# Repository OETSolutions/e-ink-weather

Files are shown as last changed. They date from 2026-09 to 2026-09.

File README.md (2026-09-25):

# Aether — Weather Display

A wall-mounted e-ink weather display. An ESP32 drives a 5.76″ 920×680 black-and-white
e-paper panel that shows current conditions, a multi-day forecast, and readings from
Home Assistant — configured from a browser-based layout editor with no code and no
recompiling.

<p align="center">
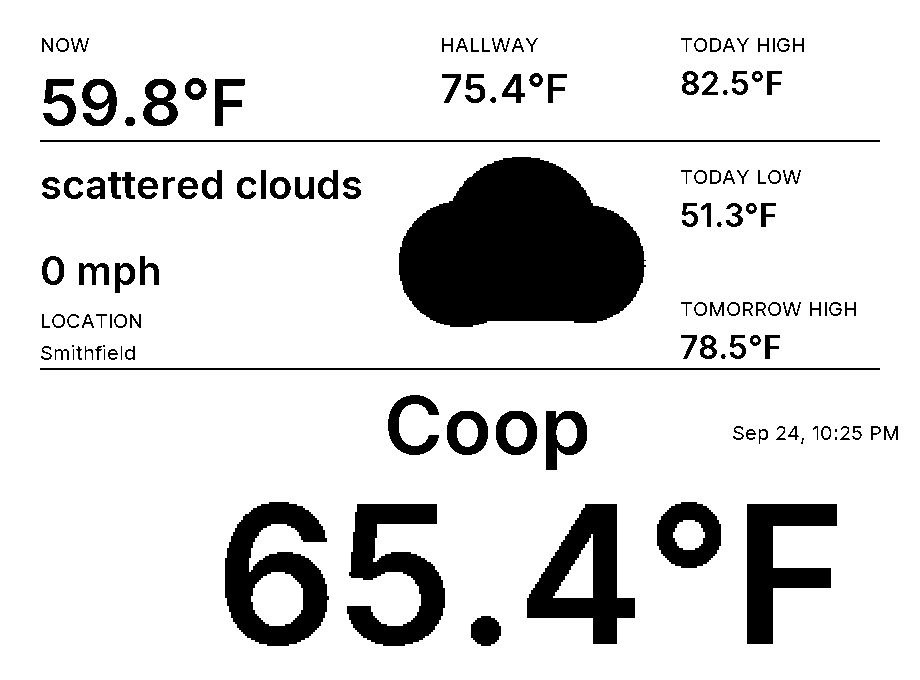
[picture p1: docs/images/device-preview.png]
The panel preview from the layout config app: temperature, conditions, the Home Assistant 'Hallway' reading, forecast highs/lows and the time of the last update
  
</p>

<p align="center"><em>What the glass shows, captured from the layout editor's preview. Everything on
screen — headings, boxes, dividers, icons and values — is placed by the layout editor below, not
hard-coded in the firmware.</em></p>

<table>
<tr>
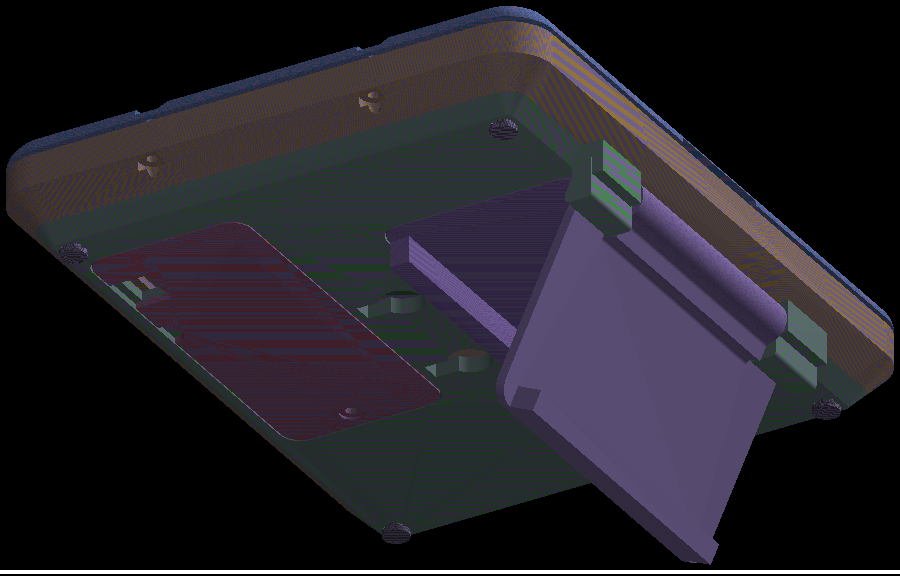
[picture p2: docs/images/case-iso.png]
CAD render of the case from an angle
<td width="50%"></td>
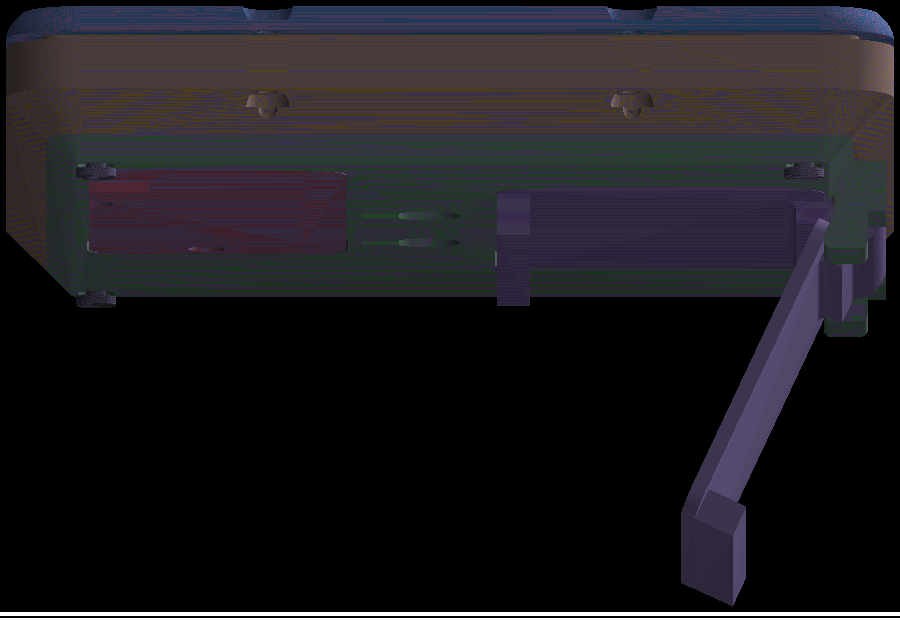
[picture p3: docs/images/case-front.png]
CAD render of the case from the side/front, showing the printed kickstand
<td width="50%"></td>
</tr>
<tr>
<td align="center"><em>Case, rear cover and printed hinge (CAD)</em></td>
<td align="center"><em>Side profile with the folding kickstand (CAD)</em></td>
</tr>
</table>

Built by **OETSolutions**.

---

## What it is

The device fetches weather from OpenWeatherMap and readings from Home Assistant, draws
them onto an e-ink panel that keeps its image even when unpowered, and serves its own
configuration web app. You point a browser at the display's IP address, arrange the
layout visually, and save — the device stores the layout and redraws.

It runs two ways:

- **Mains / always-on** — stays awake, serves the web app, and refreshes on a schedule.
- **Battery** — wakes on an interval, fetches, redraws, and goes back to deep sleep.

Power source is detected automatically from the battery voltage, and can be overridden.

## Features

- **Visual layout editor** in the browser — drag, resize and bind value boxes on a
  to-scale 920×680 canvas that shows the real 1-bit output.
- **Live preview with real data** — the editor asks the device what it actually resolved,
  so the preview matches the panel instead of guessing.
- **Two independent refresh cadences** — Home Assistant on a fast interval, OpenWeatherMap
  on a slower one (its data only updates ~every 10 minutes and its free tier is capped).
- **Multiple pages** with scheduled auto-rotation, each page with its own layout and dwell.
- **Data bindings** — OWM current conditions and forecast, Home Assistant entities (REST),
  each with per-field formatting (decimals, prefix/suffix, fallback) and thresholds.
- **Alerts** — user-defined per-field thresholds *and* official OWM severe-weather alerts.
- **Any weather product** — One Call 3.0 or the free Current + 5-day/3-hour endpoints,
  auto-detected from the API key.
- **Partial refresh** — only changed values are redrawn, with a periodic full refresh to
  clear ghosting.
- **Captive-portal and BLE provisioning** — no credentials are ever compiled in.
- **Firmware update over the network**, from GitHub releases or by uploading a `.bin`
  from the browser, with rollback protection.
- **Thermal guard** and a **last-good-image** policy: a failed fetch or an out-of-range
  temperature leaves the previous screen up rather than drawing garbage.

## How the pieces fit together

```
                    ┌─────────────────────────────┐
   browser ────────▶│  config web app (TypeScript) │  layout editor, live preview,
   (editor)         │  runs in browser OR on-device│  credentials, firmware update
                    └──────────────┬──────────────┘
                                   │ REST  (config, artwork, values, OTA)
                    ┌──────────────▼──────────────┐
   internet ───────▶│   ESP32 firmware (ESP-IDF)   │──SPI──▶ e-ink panel 920×680
   OWM, GitHub      │   fetch · render · serve     │
                    └──────────────┬──────────────┘
   Home Assistant ────────────────┘  (REST)
```

The **firmware never invents a position or a label.** The web app renders the static layer
of each page (backgrounds, headings, box outlines, icons) to a 1-bit bitmap and uploads it;
the ESP32 stores it and stamps only the *changing values* on top at each refresh. That means
a layout change ships instantly — no firmware rebuild — while the device keeps full control
of what it draws.

## Repository layout

```
eink_weather/
├── code/
│   ├── firmware/            ESP-IDF project (PlatformIO), C
│   │   ├── components/      app, api, epd, net, prov, webui, …
│   │   ├── lib/             pure, host-testable logic (datasrc, layout, owmcount, …)
│   │   ├── test/            ~510 host unit tests (run on your Mac, no hardware)
│   │   ├── tools/           generators (fonts, icons, QR, boot logo) and bench scripts
│   │   ├── assets/          generated data blobs
│   │   └── platformio.ini   pinned ESP-IDF 5.5.x toolchain
│   ├── webapp/              layout config app (TypeScript, Vite)
│   │   └── src/             model, canvas/editor, ui, transfer, presets
│   ├── docs/                spec + implementation plan
│   └── tools/               fixture / secret-header generators
├── work/                    CAD (FreeCAD), FPC and datasheet study, case renders
└── docs/images/             images used by this README
```

## Building

### Firmware

```sh
cd code/firmware
pio run                     # build
pio run -t upload           # flash over USB
pio test -e native          # host unit tests (no hardware needed)
```

ESP-IDF **5.5.x** is pinned in `platformio.ini` (both the framework and the platform —
floating either one breaks the build on a clean machine). The app image is ~1.8 MB, and
**the embedded web app shares the OTA slot**, so its size is budgeted and checked at build
time.

Secrets (WiFi, OWM key, HA URL/token) are **never compiled in** — they are entered on the
device (captive portal or BLE app) and stored in NVS. A per-machine header is generated
from a gitignored file for bench use only.

### Web app

```sh
cd code/webapp
npm install
npm run dev                                   # dev server, proxies /api to the device
npm run build:device                          # build + embed into ESP32 flash
EINK_DEVICE=http://192.168.2.34 npm run dev   # point the proxy at a device
```

The built app is embedded in the firmware, so **a web-app change is not live on the device
until you rebuild and reflash** — `npm run build:device` regenerates the embedded bundle,
which the next firmware build picks up.

### Flashing a running device over the network

Three ways, depending on the situation:

| Method | Use it when |
|---|---|
| `pio run -t upload` | The board is on USB. |
| `POST /api/firmware` | You have a `firmware.bin` and the device is on the LAN. |
| `POST /api/ota/update` | You published a GitHub release and want the device to pull it. |

The LAN upload takes the raw image over HTTP:

```sh
curl --data-binary @.pio/build/esp32dev/firmware.bin http://<device-ip>/api/firmware
```

Both network paths leave the new image **on probation**: the bootloader reverts to the
previous image unless the new one both boots *and* completes a refresh. Both are gated by
the optional access token (they replace firmware — a device takeover otherwise).

## Configuration

Open `http://<device-ip>/` in a browser. The editor covers:

- **Location** — a map picker for exact coordinates, plus an optional zip code.
- **Layout** — the canvas editor: value boxes, dividers, headings, background pictures.
- **Pages** — rotation order, per-page dwell, and the two refresh cadences.
- **Weather product** — auto / One Call 3.0 / free endpoints.
- **Credentials** — OWM key and Home Assistant URL/token (stored on the device).
- **Access** — an optional token that gates every mutating request.
- **Firmware** — check for updates, or upload a `.bin` directly.

### The two refresh cadences

Two numbers, deliberately separate:

- **Refresh Home Assistant every (seconds)** — how often the device wakes and redraws.
  Home Assistant is your own server, so this can be as short as you like.
- **Refresh weather data every (seconds)** — how often the weather is re-fetched.
  OpenWeatherMap publishes new data only about every 10 minutes and its free tier allows
  1000 calls a day, so fetching it on every wake wastes the quota on values that have not
  changed. Between weather fetches the display keeps its last readings.

A weather interval shorter than the Home Assistant one is not possible and is raised to
match it.

## Status

Complete and running on hardware. The firmware passes ~510 host tests and the web app ~220;
both are gated in CI, which also blocks releases. Firmware updates from GitHub releases are
verified end-to-end, and an image can be flashed over the LAN or by uploading it from the
browser.

## Specification

The full requirements and the implementation plan live in
[`code/docs/specs/`](code/docs/specs/) and [`code/docs/plans/`](code/docs/plans/).

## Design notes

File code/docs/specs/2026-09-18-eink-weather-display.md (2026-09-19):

# E-Ink Weather Display — Specification

**Status:** Draft for approval
**Date:** 2026-09-18
**Authors:** cbrown + Claude
**Version:** 0.1

---

## 0. How to read this document

This spec is the **single source of truth** for what gets built. Every requirement has a
stable ID (`FR-x`, `NFR-x`, `HW-x`, `IF-x`) so that tests can cite it and so that "done"
can be checked rather than assumed. Where a requirement depends on a fact that is not
verified, it is marked:

- **[VERIFIED]** — grounded in a primary source quoted in §12, or in the repo's own
  datasheets/demo code.
- **[ASSUMED]** — a reasonable engineering choice, documented so it can be challenged.
- **[OPEN]** — genuinely unresolved; carries an explicit question and a fallback plan.

Nothing in this document may be implemented on the strength of an unmarked claim.

---

## 1. Goal

Build a two-part system that puts a configurable, beautiful weather dashboard on a
5.76″ e-ink panel driven by an ESP32:

1. **Firmware** on the Good Display **ESP32-M1** board that fetches weather + Home
   Assistant data, renders the dashboard to the panel, and serves a device config API,
   OTA, and its own web UI.
2. **A web configuration app** where the user designs the layout visually — drag,
   resize, bind widgets to data sources, set alert rules, define multiple pages — and
   saves/loads configurations as local files.

**Primary intent (this phase):** display these specific values, well:

- `sensor.upstairs_hallway_temperature` (Home Assistant)
- `sensor.64b708cfe0fc_sensor_2_temperature_f` — outside coop temperature (Home Assistant)
- Current conditions and forecast for the user's location (OpenWeatherMap)
- A location picked precisely on a map, plus a zip code for the general area

…but the system must be **fully general**: any data source, any size, any position on
screen, all configured through the web UI without touching firmware.

**Non-goal for this phase:** colour/multi-panel support, touch input, frontlight (this
panel is purely reflective), and any cloud service other than OpenWeatherMap.

---

## 2. Hardware platform

### 2.1 Board: Good Display ESP32-M1

**[VERIFIED]** The board is an **ESP32-WROOM-32D** (ESP32-D0WD, dual-core, 4 MB flash,
**~320 KB usable SRAM, no PSRAM**) SPI e-paper driver board. Published outside
dimensions 66 × 48 × 1.0 mm (modeled 48 × 66 mm). It carries: USB-C (via **CH340C**
USB-serial), 3.7 V Li-ion connector (SH1.0) with **LTC4054** charger, power switch,
microSD socket, a KEY button, RST/BOOT buttons, a frontlight circuit (unused here), touch
FPC connectors (unused here), and the **P5 24-pin e-paper FPC**.

### 2.2 Panel: GDEH0576T81

**[VERIFIED]** 920 (H) × 680 (V) px, **198 dpi**, active area 117.668 × 86.972 mm,
outline 125.4 × 99.5 × 0.9 mm, 28.08 g. Controller **SSD2677**. Purely reflective — no
frontlight, no touch. Native orientation **landscape**.

- **Operating temperature 0…50 °C**; storage −25…60 °C. **[VERIFIED]**
- **600 mAs** typical per panel update; **1–3 µA** deep-sleep current. **[VERIFIED]**

> **HW-1** The firmware shall treat **0 °C as a hard lower bound for reliable
> operation**, and shall surface a warning state rather than render garbage if the
> controller's reported temperature is outside its operating range.
>
> **[MEASURED 2026-09-18 — the guard needs a fourth state.]** On this hardware the
> SSD2677's internal sensor does **not** return live ambient temperature: `0x40` TSC
> reads a constant **−15 °C**, `0x43` TSR a constant **−1 °C**, and the datasheet's TSE
> offset register (`0x41`) moves **neither** across all 8 codes. This is not a transport
> fault — the same read path returns the datasheet-correct `0x07` from REV (`0x70`) and
> `0x00` from an unused register, and REV is the documented power-on value. The panel's
> I²C external-sensor lines (`TSCL`/`TSDA`, pins 6/7) reach GPIO22/21, but GPIO21 doubles
> as the microSD `CS` and no external sensor is fitted.
>
> Consequence: **an unreadable sensor must not be treated as cold.** Folding it into
> `THERMAL_TOO_COLD` (the plan's first draft) makes the guard block *every* render
> forever on any unit that reports a constant — which is exactly what this bench unit
> does. The guard therefore returns `THERMAL_UNKNOWN` for an absent/unusable source, and
> the caller renders and logs. `THERMAL_TOO_COLD`/`TOO_HOT` are reserved for readings
> that actually came from a live source.

### 2.3 Pin map — the hardware contract

**[VERIFIED]** Decoded from the schematic (`code/ESP32-M1-SCH-20260307.pdf`) and
cross-checked against both the vendor demo and Espressif's `pins_arduino.h`. The
schematic labels module pins with Arduino *analog* aliases, which is why the table looks
unusual.

| Function | Arduino alias | GPIO |
|---|---|---|
| EPD **BUSY** | A14 | **13** |
| EPD **RES / RST** | A15 | **12** |
| EPD **D/C** | A16 | **14** |
| EPD **CS** | A17 | **27** |
| EPD **SCLK** | — | **18** |
| EPD **SDI / MOSI** | — | **23** |
| microSD **CS** (`SPI_CS_SD`) | — | **21** |
| GT30 font chip **CS** (`SPI_CS_GT30`) | A13 | **15** |
| **VBAT sense** (`VREF`, R8 300K / R9 1M divider) | A19 | **26** |
| KEY button (`KEY1`) | A18 | **25** |
| USB serial TX / RX | — | 1 / 3 |

> **HW-2** The e-paper, microSD and (if populated) the GT30 font chip **share one SPI
> bus**. Firmware shall arbitrate the bus with per-device chip-selects and shall never
> drive two CS lines low simultaneously.

> **HW-3 Battery/USB auto-detection.** The user requires automatic detection of
> battery vs. mains. **No dedicated USB-present or charge-status pin is confirmed
> available** — the `CHRG` net's destination GPIO could not be confirmed from the
> schematic, and `CHP_PU`/`SENSOR_VP`/`SENSOR_VN` turned out to be the module's own pin
> names, not board nets. **[VERIFIED: absence of confirmation]**
>
> Primary method: read the **VBAT sense network** — `VREF` = VBAT × 1 M/(300 K + 1 M) =
> **VBAT × 0.769**, on **GPIO26**. Interpretation:
> - VBAT ≥ ~4.15 V and slowly rising → on USB/charging.
> - VBAT ≤ ~4.10 V and falling → on battery.
> - **[ASSUMED]** these thresholds; they are Li-ion-typical but must be measured on the
>   real unit and made configurable.
>
> **Critical caveat [VERIFIED]:** GPIO26 is **ADC2_CH9**, and on classic ESP32 **ADC2 is
> unusable while WiFi is active** (Espressif documents this). Therefore the battery
> reading **must be taken before WiFi is brought up** (or after it is torn down), and
> the design must never read the ADC mid-session while connected. This constraint shapes
> the boot sequence (§5) and is a genuine architectural driver, not a detail.

> **HW-4** Firmware shall **probe at runtime** whether the GT30 font chip responds, and
> shall not depend on it (see HW-6). **[VERIFIED 2026-09-18 ON HARDWARE: the schematic
> silk reads `FONT - GT30L32S4W (Reserve)`, but the chip IS POPULATED on the ESP32-M1.**
> The probe reads the 8×16 ASCII glyph for `'A'` at `0x1DD990` and matches it
> byte-for-byte against LibDriver's reference. The chip has **no read-ID command** (only
> `0x03` read and `0x0B` fast-read), so presence is established by reading known content —
> a floating MISO cannot reproduce a real glyph. Data returns on **SPI_MISO = GPIO19**,
> wired to the GT30's pin 2 (`SO`).]

> **HW-5** Panel driving shall **preserve the vendor's exact undocumented init
> register sequence**. **[VERIFIED]** The public SSD2677 datasheet (Rev 1.1) documents
> only ~20 commands; the vendor's `EPD_init()` writes `0x00 PSR`, `0x30`, `0x62 HTOTAL`,
> `0x65 GSST`, `0xE0`, `0xE6`, `0xE7`, `0xE9`, **none of which appear in the datasheet**.
> They are vendor-proprietary. The firmware must reuse them verbatim, may not
> "clean up" the driver from the datasheet, and must be able to reproduce the vendor
> demo's output exactly as a regression baseline.

### 2.4 Framebuffer format

**[VERIFIED]** The vendor demo's image arrays are `unsigned char gImage_N[78200]` =
920 × 680 / 8, **1 bit per pixel, MSB-first** (78,200 bytes = 76.4 KiB). The demo then
expands 1 bpp → **2 bpp (4 grey levels)** before writing register `0x10` (DTM), which the
SSD2677 datasheet confirms is a 2-bit-per-pixel buffer.

> **HW-6** The rendering pipeline's canonical on-wire format shall be **1 bpp, 78,200
> bytes, MSB-first, row-major**. A 4-grey 2 bpp buffer (152.8 KiB) exceeds comfortable
> headroom alongside WiFi/TLS buffers on a 320 KB part **[ASSUMED: must be measured]**;
> 4-grey output, if used, shall be produced via the demo's 1→2 bpp expansion so only one
> 1 bpp buffer need exist in RAM.

### 2.5 SPI and transfer performance

> **HW-7** **[VERIFIED: the SSD2677 datasheet's entire SPI timing table reads "TBD"]**
> There is **no published maximum SPI clock**. The vendor demo uses **bit-banged
> software SPI**, which is very slow for a 78,200-byte frame.
>
> Plan: bring up the driver on **software SPI first** (proven, matches the demo), then
> move to **hardware SPI** as a measured, incremental optimization with a known-good
> reference image and a visible failure signal. The hardware-SPI clock is **[OPEN]** and
> shall be a configurable constant tuned against real hardware, defaulting conservatively.

---

## 3. System architecture

### 3.1 Two deliverables, one contract

```
 ┌────────────────────────┐         ┌───────────────────────────────┐
 │  WEB CONFIG APP        │         │  ESP32 FIRMWARE               │
 │  (browser, offline-cap.)│        │  (ESP32-M1)                   │
 │                        │         │                               │
 │  • 920×680 layout canvas│  HTTP  │  • config API (REST)          │
 │  • drag / resize       │ <─────> │  • NVS persistent storage     │
 │  • data binding        │  /api   │  • data sources: OWM, HA      │
 │  • alert rules         │         │  • renderer                   │
 │  • pages               │  Files  │  • EPD driver                 │
 │  • SAVE / LOAD files   │ <─────> │  • web UI (same app, built-in)│
 └────────────────────────┘         └───────────────────────────────┘
        (also served BY the device — user chose "both")
```

### 3.2 Rendering architecture — the load-bearing decision

The user chose: **static pre-render + on-device values**, while explicitly asking to
*"retain the ability to do on-device easily if this becomes preferable in the future."*

> **FR-1 — Renderer abstraction.** The system shall define a **renderer interface** with
> (at least) two implementations behind it:
> 1. **Composite renderer (primary):** the web app pre-renders the *static* layer
>    (background, frames, labels, icons, static text) to a 1 bpp 78,200-byte bitmap,
>    uploads it once; the firmware stores it and blits it each refresh, then draws only
>    the *dynamic value fields* on top.
> 2. **Full on-device renderer (deferred):** the firmware consumes the layout spec and
>    renders everything itself, including fonts and text layout.
>
> No code outside the renderer interface may assume which implementation is active.

> **FR-2 — Field model.** A layout is a set of **widgets**, each with a geometry
> (x, y, w, h), a **data binding**, and a **rendering role** (static or dynamic). Widgets
> marked dynamic must be re-drawn on every refresh from current data.

> **FR-3 — Value drawing.** On-device dynamic value drawing shall support at minimum:
> numeric and text values, alignment (left/centre/right, top/middle/bottom), a
> configurable font size, and a "fit to box" mode that shrinks text to fit its widget
> rather than overflowing. **[ASSUMED: this is the minimum for the listed use case.]**

### 3.3 Fonts

The user requires fonts that *"look extremely good"* and pointed at the board's GT30
font chip.

> **HW-6 / FR-4** The GT30L32S4W is marked **"(Reserve)"** on the schematic — a
> reserve/DNP footprint — so it **cannot be assumed present**. The firmware shall:
> 1. **Probe** for it at boot and cache the result;
> 2. **Use it only if present** and only for glyphs it actually provides;
> 3. **Always retain a built-in flash-resident font path** that works with the chip
>    absent.

> **FR-4a — Font strategy (DECIDED). [VERIFIED: library characteristics]**
> **Pre-rendered 1-bit bitmap font atlases, generated at build time, baked into the
> firmware and used by the web app's preview.** Rationale and specifics:
> - **Why not a runtime font engine:** the panel is 1-bit (HW-6) at 198 dpi, where
>   **anti-aliasing is impossible** — grey fringes become visible dots. The crispest
>   result comes from glyphs **hinted and rasterised for the exact pixel size** once, at
>   build time, then blitted. A runtime TTF rasteriser burns RAM/flash and produces
>   softer output. **[ASSUMED — strong engineering judgment, not a datasheet claim.]**
> - **Why the atlas approach beats a generic library:** `U8g2` **[VERIFIED: widely used
>   for monochrome displays; Unicode-capable]** has excellent built-in fonts but pulls in
>   a rendering model the vendor's undocumented EPD init does not need. Baking our own
>   atlases keeps the firmware free of a display library that could fight the vendor
>   sequence (HW-5) and lets the **exact same atlas** drive the web-app preview, which is
>   what makes NFR-4 ("preview matches panel bit-for-bit") achievable.
> - **Atlas generation:** a build step converts chosen faces (Inter / IBM Plex / Roboto
>   class — clean, high-x-height, superb at small sizes **[ASSUMED]**) into 1-bit atlases
>   for a fixed ladder of sizes tuned to 198 dpi (e.g. body ≈ 18–22 px, value ≈ 56–72 px).
>   Threshold, do **not** dither, for text — dithering makes type look dirty.
> - **The GT30 chip, if populated, is an accelerator only** — never a dependency.
>
> **FR-4b** Only glyphs actually used by a configuration need to be present, so atlases
> may be **subset per configuration** at push time to save flash. **[ASSUMED: defer until
> flash pressure is measured; full ASCII+latin-1 first.]**

### 3.4 Data sources — pluggable

> **FR-5** The firmware shall define **one data-source interface** with **two
> interchangeable implementations**: **Home Assistant REST** and **MQTT**. The user
> chose "both, pluggable" and both shall exist; REST ships first. Swapping must be a
> config change, not a code change.

> **FR-5a — HA REST, and the key optimisation. [VERIFIED]**
> - Auth is `Authorization: Bearer <long-lived access token>`, obtained from the HA user
>   profile page. `GET /api/states/<entity_id>` returns one entity as
>   `{entity_id, state, last_changed, last_updated, attributes{...}}`; a **404 means the
>   entity does not exist** — which gives the web app a clean way to *validate* an entity
>   id the user types (FR-23).
> - **`GET /api/states` returns *every* entity in one array.** That is one round-trip but
>   the payload is large (hundreds of entities) and would be a needless memory spike on a
>   320 KB part. **Use it only in the web app** (for entity discovery), never on-device.
> - **The on-device design: `POST /api/template`.** HA will render a template server-side
>   and return the result as plain text. So the device sends **one small POST** naming
>   exactly the entities its current layout needs, and receives **one small response** —
>   e.g. `{{ states('sensor.upstairs_hallway_temperature') }}|{{ states('sensor.64b708cfe0fc_sensor_2_temperature_f') }}`
>   ⇒ `68.4|41.2`. This is strictly better than N per-entity GET calls and far better than
>   pulling `/api/states`. **The device derives the template from its own layout's bound
>   entities, so adding a widget needs no firmware change.** JSON output is also possible
>   via a template that emits a JSON object, if structured values are preferable.
> - HA weather forecasts are available via
>   `POST /api/services/weather/get_forecasts?return_response` with
>   `{"entity_id": "...", "type": "daily"}` **if** the user later wants HA-sourced
>   forecasts alongside OpenWeatherMap. **[Not required for this phase.]**
>
> **FR-5b — Timestamp hygiene.** HA `state` values are **strings**, and a sensor can be
> `"unavailable"`/`"unknown"`. The data layer shall therefore validate, not cast blindly,
> and shall carry `last_updated` through so the layout can show and the alert logic can
> detect **stale** data. **[ASSUMED — this is the main correctness trap in consuming HA.]**

> **FR-5c — MQTT, and its real cost. [VERIFIED]** An HA entity's state is **not**
> published to MQTT by default. The user must enable the **`mqtt_statestream`**
> integration (plus the `mqtt` integration, i.e. a broker such as Mosquitto). Its
> documented topic form is **`base_topic/domain/entity/state`** — e.g.
> `homeassistant/sensor/upstairs_hallway_temperature/state` — with optional
> `publish_attributes` and `publish_timestamps` adding sibling topics
> (`.../last_updated`, and one topic per attribute).
> - Values are **JSON-serialised before publishing**, so a string state arrives quoted
>   (`"on"`). The parser must account for this.
> - **`mqtt_statestream` is flagged in HA's own docs as a *legacy* integration**
>   ("community maintained"). **[VERIFIED]** The spec shall therefore **not depend on it
>   as the only path** — which is exactly why REST ships first and MQTT is the pluggable
>   alternative (FR-5). The setup guide shall state the HA-side configuration the user
>   must add.
> - **Deep-sleep fit [ASSUMED, engineering judgment]:** MQTT needs a persistent broker
>   session, and a device that sleeps has to reconnect each wake — so MQTT's push
>   advantage largely evaporates in battery mode and it is **most useful in always-on
>   mode**. This informs FR-5's "REST first" ordering and shall be stated in the docs
>   rather than discoverered later.

> **FR-6 (OpenWeatherMap)** The provider shall support **both** OpenWeatherMap products —
> **One Call API 3.0** and the legacy free **Current Weather + 5-day/3-hour Forecast**
> — selectable by **config toggle**, and shall **auto-detect from the API key where
> possible** (probe One Call 3.0; fall back on the documented not-subscribed response).

> **FR-6a [VERIFIED]** The primary endpoint is
> `https://api.openweathermap.org/data/3.0/onecall?lat={lat}&lon={lon}&exclude={part}&units={units}&appid={KEY}`.
> - `lat`/`lon` **required**; `units` optional (`standard`|`metric`|`imperial`;
>   **`imperial` gives °F and mph**, which is what the user's entities use).
> - Returns **current weather, minute (1 h), hourly (48 h), daily (8 d), and
>   government weather alerts** — so **alerts come free with the same single call**,
>   which is why One Call 3.0 is the preferred product (FR-14).
> - **One Call 3.0 requires the separate "One Call by Call" subscription, which includes
>   1,000 calls/day free but requires a card on file.** **[VERIFIED]** At a 10–15 minute
>   refresh that is ~96–144 calls/day, comfortably inside the free tier. The firmware
>   shall nonetheless **count and cap daily calls** and surface the count in `/api/status`,
>   so a bug cannot silently burn the quota.
> - The free legacy endpoints (Current Weather `data/2.5/weather`, 5-day/3-hour forecast
>   `data/2.5/forecast`) require no card but carry **no official alerts** — the exact
>   trade-off FR-7 handles.

> **FR-7** Official severe-weather alerts depend on One Call 3.0. If the configured
> product does not provide them, the alert feature shall degrade explicitly (state that
> official alerts are unavailable) rather than silently showing nothing.

### 3.5 Power and sleep

> **FR-8** Firmware shall support **both** modes, user-selectable / auto-detected
> (HW-3): **deep-sleep battery mode** and **always-on mains mode**. Battery detection
> happens **before WiFi init** (HW-2 caveat).
>
> Auto-detection is **inferred** and therefore fallible: **[VERIFIED — schematic]** this
> board has no confirmed USB-present or charge-status pin (the VBUS net and the LTC4054's
> `CHRG` output exist, but neither destination GPIO resolves), so the mode is derived from
> the VBAT divider alone. The configuration shall therefore carry an explicit
> **`powerMode`** of `'auto' | 'always-on' | 'battery'` (default `'auto'`) so the user can
> override a wrong guess. Detection shall fail **toward battery**, because sleeping too
> eagerly costs a slower refresh while failing to sleep costs the entire battery. The
> residual limitation is inherent to inferring from one signal: a pack held **flat** at
> or above the threshold is indistinguishable from mains, so a full cell whose voltage
> is not measurably falling will read as USB. That case is what the `powerMode` override
> exists for; the trend term only separates the two when the pack is actually drooping.

> **FR-9** In deep-sleep mode the device shall wake on a configurable interval, and the
> boot path shall be ordered: **read VBAT (ADC2, WiFi off) → connect WiFi → fetch →
> render → update panel → sleep**, with the panel update and sleep guaranteed even if a
> fetch fails (§5).

### 3.6 E-ink lifetime

The user explicitly requires proper lifetime preservation *and* demo-like speed/quality.

> **FR-10** **[VERIFIED — panel datasheet §7.5]** The panel **must be refreshed at least
> every 24 hours** or "Ghosting"/"Image Sticking" may occur. The firmware shall enforce
> a **daily full refresh** regardless of the configured update interval.

> **FR-11** The firmware shall implement a **partial-refresh-with-periodic-full-refresh**
> strategy: mostly partial updates for speed and low flicker, with a full refresh after a
> configurable number of partials **[ASSUMED default 5, per the vendor demo's comment]**
> and at the daily boundary (FR-10).

> **FR-12** The firmware shall **always issue the deep-sleep command** after an update
> and shall re-initialise before every full update, per the vendor's documented
> requirements **[VERIFIED]**. It shall not leave the panel powered between updates.

> **FR-13** The firmware shall read the controller's internal temperature (command
> `0x40`, which returns °C directly per the datasheet) and apply the vendor's
> temperature-compensated waveform selection, preserving the demo's behaviour.
>
> **[MEASURED 2026-09-18]** `0x40` on this unit returns a constant −15 °C regardless of
> ambient, so the waveform it selects is a *fixed* cold-temperature LUT (the `<=5 °C`
> entry, value 232), not a temperature-tracking one. The vendor demo has the same
> exposure and simply never noticed. This is safe — the LUT ladder is monotone and the
> cold entry is a valid waveform — but it is **not** compensation, and the code must not
> claim it is. Revisit if a working ambient source (external I²C sensor, or a live
> internal reading on a different unit) becomes available. See HW-1.

### 3.7 Alert bars

> **FR-14** The system shall support **two** alert mechanisms, both per the user's choice:
> 1. **User-defined threshold rules** per bound field (e.g. *temp_f > 100 → red bar*,
>    *wind_mph > 25 → amber bar*), editable in the web UI, working for **any** bound
>    source including Home Assistant entities.
> 2. **OpenWeatherMap official severe-weather alerts** rendered when present (subject to
>    FR-7).
>
> Alert rendering shall be a first-class widget type with configurable severity levels,
> colours (mapped to grey levels on a mono panel), and text.

### 3.8 Paging

> **FR-15** The system shall support **multiple pages**, each with its own layout,
> bindings, and refresh interval. **[VERIFIED: user chose scheduled auto-rotation]** The
> device shall cycle pages automatically on a configurable schedule.

> **FR-16** Paging must be optional; a single-page configuration shall behave identically
> to today's requirement.

### 3.9 Initial layout (this phase's deliverable)

> **FR-17** The project shall ship a **default layout** implementing the user's stated
> intent: upstairs hallway temperature, outside coop temperature, current conditions,
> forecast, and location/zip display — with sensible alert rules pre-configured.

---

## 4. Web configuration app

### 4.1 Delivery

> **FR-18 [VERIFIED: user chose "both"]** The app shall be buildable two ways from one
> codebase:
> 1. **Local dev:** `npm run dev` for rich, fast editing against a device on the LAN.
> 2. **Embedded:** the production build is flashed into the ESP32 and served by the
>    device itself at its IP, with no install.

> **FR-19** Both modes shall share the same API client contract so behaviour is identical.

> **FR-19a — Framework (DECIDED): vanilla TypeScript + Vite, no UI framework.**
> Rationale:
> - The app is **one screen with one canvas** plus a property panel. A component
>   framework (React/Vue/Svelte) adds a build/runtime dependency and bundle weight for
>   little benefit here, and bundle weight matters because this build must also be
>   **served from an ESP32's 4 MB flash** (FR-18).
> - The hard part is canvas interaction (drag, resize, snapping), not component
>   composition. **A small purpose-built interaction layer over a `<canvas>` is more
>   predictable than fighting a DOM-based drag library** for pixel-exact 1-bit output.
> - **Vite** gives fast dev with HMR (`npm run dev`) and a small production build with
>   an easy single-file asset step for embedding in firmware. **[VERIFIED: Node 26 /
>   npm 11 present locally.]**
> - Escape hatch recorded: because the state layer is plain TS + a typed config model
>   (§IF-1), a framework could be introduced later without rewriting the model.
>
> **[ASSUMED — this is a judgment call, flagged deliberately.]** If the user prefers
> React, React + `react-rnd` is the natural alternative; nothing else in the spec depends
> on this choice.

### 4.2 Editor requirements

> **FR-20** The editor shall present a **fixed 920 × 680 pixel canvas** representing the
> panel exactly, with zoom/pan, and shall render a truthful 1-bit preview (what you see
> is what the panel shows).

> **FR-21** Widgets shall support **drag**, **resize** (edge/corner handles), **grid
> snapping**, **alignment guides**, and a **z-order** control.

> **FR-22** A **property inspector** shall expose, per widget: geometry, data binding,
> static/dynamic role, font/size/alignment, formatting (units, decimals, prefixes),
> and alert rules.

> **FR-23** The app shall support **data binding** to: OWM current fields, OWM forecast
> fields, OWM alerts, and arbitrary Home Assistant entities (chosen by entity id, with a
> discovery/validation step against the configured HA instance).

> **FR-24** The app shall include a **map picker** for precise lat/lon, and a **zip code**
> field for general location.

> **FR-25** The app shall manage **multiple pages** and their rotation schedule.

> **FR-26** The app shall **save and load configurations as local files**, and push a
> configuration to the device. **[VERIFIED: user requirement]**
>
> **FR-26a — Format: download/upload JSON, not the File System Access API. [VERIFIED]**
> MDN classes `showSaveFilePicker()`/`showOpenFilePicker()` as **"Limited availability …
> not Baseline … Experimental"**, requiring a **secure context (HTTPS)** and transient
> user activation. That rules it out as the primary mechanism for a device served over
> plain HTTP on a LAN IP. **Design:** a versioned `.json` config downloaded/uploaded via
> a normal anchor/`<input type=file>`, which works everywhere; optionally *enhance* with
> the File System Access API **only when `window.showSaveFilePicker` exists** (progressive
> enhancement, never required). `localStorage` holds working state and recent configs.
>
> **FR-26b** A saved config file shall be self-describing: it embeds `schemaVersion` and
> a `generator`/`createdAt` stamp so a future version can migrate it or refuse it clearly
> rather than silently mis-reading it.

> **FR-27** The app shall show a **live or on-demand preview** rendered with real fetched
> data before pushing to the device.

---

## 5. Firmware behaviour

### 5.1 Boot / wake sequence

> **FR-28** The boot path shall be, in order:
> 1. Initialise NVS, load config.
> 2. **Read VBAT sense (GPIO26) with WiFi off** → decide power mode (FR-8, HW-3).
> 3. Initialise panel and render the *last known* state **or** a "connecting" state
>    (so a network failure never leaves a stale/blank panel).
> 4. Bring up WiFi (station; captive portal if unconfigured).
> 5. Fetch all enabled sources (with per-source timeout and retry).
> 6. Render the current page and update the panel (partial or full per FR-11).
> 7. Persist any needed state; deep-sleep if in battery mode.

> **FR-29** **Every** failure mode shall leave the panel showing the last good image
> plus a visible, discreet error indicator — never a blank panel or a wedged device.

### 5.2 Provisioning

> **FR-30 [VERIFIED: user chose Option 1 + BLE]** The device shall support:
> 1. **Captive-portal provisioning** on first boot / unconfigured state — a WiFi AP where
>    the user enters WiFi credentials, the OWM API key, the HA URL and token, and
>    location. Values persist in **NVS**.
> 2. **The official ESP BLE Provisioning mobile app**, current version with full update
>    support.
>
> No credentials shall ever be committed to git.

### 5.3 Config API

> **FR-31** The device shall expose a REST API for the web app: read config, write
> config, upload the static bitmap, upload per-page layouts, trigger a refresh, read
> status (last fetch, last refresh, battery voltage, RSSI, firmware version, errors).
> Exact endpoints in §6.

### 5.4 OTA

> **FR-32** The device shall support **OTA firmware update**, authenticated, with
> rollback protection (a failed new image shall fall back to the previous working one).

### 5.5 Diagnostics

> **FR-33** The device shall expose: firmware version, uptime, free heap (minimum
> watermark), WiFi RSSI, last N errors, panel refresh counts (partial/full), and battery
> voltage history — enough to diagnose a field failure remotely.

---

## 6. Interfaces (exact contracts)

> **IF-1 Config document (JSON).** The canonical configuration is a single versioned JSON
> document owned by the web app and stored in device NVS. It shall carry a `schemaVersion`
> and be forward/backward compatible by explicit migration. Full schema in
> `docs/specs/config-schema.md` (to be written with the implementation).

> **IF-2 Static bitmap transfer.** 1 bpp, 78,200 bytes, MSB-first, row-major.
>
> **IF-2a — Mechanism (DECIDED): chunked HTTP upload, with the SD card as an offline
> path.**
> - Primary: `POST /api/bitmap` with a **chunked** body (e.g. 4 KB per request, with an
>   offset/index and a finalising commit), so a 76.4 KiB upload never needs to be buffered
>   whole on a part with ~320 KB SRAM. The device streams each chunk to flash (a dedicated
>   raw partition or a filesystem file), verifies a checksum, then atomically marks the new
>   bitmap active. **An interrupted upload must leave the previous bitmap intact.**
> - Secondary (offline / no-network): the same file can be written to the **microSD**,
>   whose socket is already present and case-accessible. This exercises HW-2's bus
>   arbitration and gives a way to update a device that will not join the network.
> - **[ASSUMED: chunk size and storage target to be confirmed once flash partitioning is
>   designed; the requirement is the streaming + atomic-swap behaviour, not the exact
>   number.]**

> **IF-3 Data-source interface.** `fetch(source) -> {value, unit, timestamp, error}`
> semantics, identical for OWM, HA-REST and MQTT, so widgets are source-agnostic.

> **IF-4 REST endpoints.** `GET/PUT /api/config`, `POST /api/bitmap`, `POST /api/refresh`,
> `GET /api/status`, `POST /api/provision`, `POST /api/ota` — final naming and payloads
> fixed during implementation, documented in `docs/specs/api.md`.

---

## 7. Non-functional requirements

> **NFR-1 Reliability.** The device shall run for weeks unattended and recover
> automatically from WiFi loss, DNS failure, TLS failure, and API errors, without a power
> cycle. This is the user's explicit complaint about the vendor demo.

> **NFR-2 Memory.** Firmware shall operate within the ESP32-WROOM-32D's ~320 KB SRAM with
> **no PSRAM**, maintaining a documented minimum free-heap watermark under worst-case
> (TLS + WiFi + render) load. A full 1 bpp framebuffer is 76.4 KiB.

> **NFR-3 Power.** Deep-sleep current shall approach the panel's 1–3 µA floor with the
> panel and radios off; the firmware shall not leak power in sleep.

> **NFR-4 Display quality.** Text shall be crisp at 198 dpi with no anti-aliasing
> artifacts; the preview in the web app shall match the panel output bit-for-bit.

> **NFR-5 Lifetime.** Panel refresh strategy shall satisfy FR-10…FR-13.

> **NFR-6 Testability.** All pure logic (data model, layout maths, alert evaluation,
> formatting, config migration, bitmap generation) shall be **unit-testable on the host
> without hardware**. Hardware paths shall be isolated behind thin interfaces.

> **NFR-7 No silent assumptions.** Every requirement carries a test that fails when the
> requirement is not met — "done" is defined by the tests, not by assertion.

---

## 8. Repository layout

**[VERIFIED: user chose the current directory]**

```
eink_weather/                  <- git root
  code/                        <- working dir
    ESP32-M1-SCH-*.pdf         (reference, unchanged)
    SSD2677(Rev1.1)N_driver_ic.pdf
    GDEH0576T81_Arduino_demo_code/   (reference, unchanged)
    firmware/                  <- NEW  PlatformIO project
    webapp/                    <- NEW  web config app
    docs/
      specs/                   <- NEW  this spec + schema/api docs
      plans/                   <- NEW  implementation plan
```

---

## 9. Tech stack

### 9.1 Firmware framework — DECIDED: ESP-IDF

**[VERIFIED]** The decision is **`framework = espidf`** in PlatformIO. Evidence:

1. **The user's crash report is real and documented.** The Arduino ESP32 TLS failures are
   not anecdote — they are a well-known class of bug with a known mechanism. Multiple
   primary issue reports on `espressif/arduino-esp32` show exactly this signature:
   - **#566** — *"Any HTTPS connection results in a stack overflow error … `***ERROR*** A
     stack overflow in task loopTask has been detected`"* the moment `client.connect()`
     runs.
   - **#1025** — *"Latest pull causing core panic and stackoverflows"*, stack overflow in
     `loopTask`.
   - **#1260** — *"SSL Handshake still an issue … Guru Meditation Error: Core 1 panic'ed
     … Stack canary watchpoint triggered (loopTask)"* during the TLS handshake.
   - **#211** — crash/panic after a TLS handshake fails, backtrace through
     `start_ssl_client` → `WiFiClientSecure::connect` → `loopTask`.
   **Root cause [ASSUMED, well-supported]: the Arduino `loopTask` runs with a small
   default stack (~8 KB) and the TLS handshake needs more.** Arduino's `loop()` model
   gives the developer no natural place to size that stack. This is precisely why the
   vendor demo appears to "crash in WiFi/SSL/webserver".

2. **PlatformIO's official ESP32 platform does not support the current Arduino core.**
   **[VERIFIED]** `platformio/platform-espressif32` issue **#1225**: *"Arduino 3.x is not
   officially supported by PlatformIO"* — the official platform remains on Arduino core
   2.x. The community workaround is the **`pioarduino` fork**
   (`https://github.com/pioarduino/platform-espressif32`), currently tracking **Arduino
   3.3.11 / ESP-IDF 5.5.5**. So an Arduino-based build would mean either depending on a
   third-party fork or pinning to a 2.x core — i.e. deliberately building on the older
   stack that has the crash bugs. **ESP-IDF, by contrast, is natively and fully supported
   by PlatformIO with no fork.**

3. **Every requirement maps to a first-party ESP-IDF component. [VERIFIED]**
   - TLS + HTTPS + certificate bundle → `esp-tls` / `esp_http_client` (+ baked CA bundle).
   - MQTT → `mqtt` client component.
   - HTTP server for the config API + device-served web UI → `esp_http_server`.
   - OTA with rollback → `esp_https_ota` + the standard dual-OTA partition table.
   - **BLE provisioning for the official app** → the `wifi_provisioning` component, which
     is *the* component Espressif's own **ESP BLE Provisioning** app (App Store / Play
     Store, "IDF v3.2 and later") is designed to talk to. This is a direct match for the
     user's requirement — no library hunting.
   - Deep sleep → `esp_sleep`.
   - Persistent config → `nvs_flash`.
   - JSON → `cJSON` (bundled).

4. **The crash class is structurally avoided, not just avoided by luck.** In ESP-IDF the
   firmware controls task creation and therefore the **stack size of every task**. The
   network work runs in a task sized for TLS, so the #566/#1260 failure mode cannot occur
   by default. This directly addresses NFR-1 and the user's stated complaint.

5. **The driver work is framework-neutral.** **[VERIFIED]** Because the vendor's EPD init
   registers are undocumented (HW-5), the firmware must *reuse the vendor's byte
   sequence* rather than adopt a third-party display library. So the usual "Arduino has
   more libraries" argument does not apply here — there is no library that helps.

6. **Testability [VERIFIED]** matches NFR-6/NFR-8 directly: ESP-IDF ships the **Unity**
   test framework and a **pytest**-driven on-device test runner, and its components can
   be built for the host, enabling the off-device unit tests the spec requires.

> **FR-35** Firmware shall be a PlatformIO project using `framework = espidf`, targeting
> the `esp32dev` board (ESP32, 4 MB flash, 320 KB RAM **[VERIFIED: matches `pio boards`]**).
> The ESP-IDF version shall be pinned explicitly in `platformio.ini` for reproducibility.
>
> **[VERIFIED: `pio pkg show platformio/framework-espidf`]** versions available to
> PlatformIO are `4.60100.0` (= ESP-IDF **6.0.1**, latest), `4.60000.0` (6.0.0),
> `3.50503.0` (**5.5.3**), `3.50400.0` (5.4.0), … Pin to the newest **5.5.x** line
> (`3.50503.0`) for this project's first release — it is mature and well inside
> component support — and treat 6.0.x as a later, deliberately-tested upgrade. **The
> pinned version is a requirement, not a footnote: an unpinned toolchain is exactly how
> a project silently changes behaviour between builds.**

> **FR-36 (counterargument, recorded deliberately)** ESP-IDF has a steeper learning curve
> and a smaller third-party-library ecosystem than Arduino. This is accepted because
> (a) the needed functionality is all first-party, (b) the display driver must be
> vendor-derived anyway, and (c) ecosystem convenience is what produced the instability
> the user is trying to escape. **If Arduino convenience is ever genuinely needed, the
> escape hatch is `framework = arduino, espidf`** — Arduino-as-a-component under ESP-IDF
> **[VERIFIED: supported by PlatformIO]**, which preserves ESP-IDF's task control while
> allowing specific Arduino libraries. This is the documented fallback, not the default.

> **FR-37** Web app: modern JS toolchain (Node 26 / npm 11 available locally
> **[VERIFIED: local environment]**). Framework choice **[OPEN — §11 Q5]**.

---

## 10. Testing strategy (defined before code)

> **NFR-8** Every requirement below shall have an automated test before it is considered
> implemented (TDD). Tests are grouped:
>
> 1. **Host unit tests (firmware, pure logic)** — run on the developer machine with no
>    hardware. Cover: config schema + migration, data-source parsing (recorded OWM/HA/MQTT
>    fixtures), alert-rule evaluation, unit/format logic, widget geometry, 1 bpp bitmap
>    encoding, page-rotation scheduling, VBAT→voltage maths.
> 2. **Hardware-in-the-loop tests (on device, manual/scripted)** — panel init produces the
>    vendor reference image; partial vs. full refresh; sleep current; WiFi reconnect
>    soak; OTA rollback; provisioning.
> 3. **Web app tests** — component tests for widgets/editor, plus end-to-end tests for
>    drag/resize/bind/save/load/push.
> 4. **Contract tests** — the web app and firmware agree on the config document and API
>    (shared fixtures, so schema drift fails a test rather than a device).
>
> **NFR-9** A **golden-image test** shall pin the firmware's rendering of the default
> layout: a known config + known fixture data ⇒ an exact expected 78,200-byte bitmap.
> Any rendering regression fails loudly.

---

## 11. Open questions

| # | Question | Status / fallback |
|---|---|---|
| Q1 | Font strategy | **RESOLVED — pre-rendered 1-bit atlases** (FR-4a); GT30 as optional accelerator only. |
| Q2 | Config save/load mechanism | **RESOLVED — download/upload JSON** (FR-26a); File System Access API as optional progressive enhancement only. |
| Q3 | Static bitmap transfer | **RESOLVED — chunked HTTP with atomic swap** (IF-2a); microSD as offline path. |
| Q4 | Firmware framework | **RESOLVED — ESP-IDF** (§9.1). Escape hatch: `framework = arduino, espidf`. |
| Q5 | Web app framework | **RESOLVED — vanilla TS + Vite** (FR-19a); React + react-rnd is the recorded alternative. |
| Q6 | GT30 font chip CS GPIO | **RESOLVED 2026-09-18 — GPIO15 (`A13`)**. Resolved by rendering the schematic at 3000 DPI and aligning the `SPI_CS_GT30` wire's x-position against the module's bottom-pin numbers, then cross-checking the alias: the pin-23 wire carries `IO15` / `A13` / `T3` / `SPI_CS_GT30`, and `pins_arduino.h` confirms `A13 = 15`. The same method reproduces the already-verified BUSY pin (A14=13), which is the control. The chip remains **DNP/reserve** — the probe still returns 0 when absent. |
| Q7 | Exact VBAT thresholds for battery/USB discrimination | **Open by design** — default 4.15 V / 4.10 V, configurable; measure on the real unit (HW-3). |
| Q8 | Is the `CHRG` charge-status net usable, and on which GPIO? | **Open** — fallback: ignore it, rely on the VBAT divider (HW-3). |
| Q9 | Chunk size + storage target for the bitmap | **Open** — resolve during flash-partition design; the streaming/atomic requirement stands (IF-2a). |
| Q10 | Font faces and the exact size ladder for 198 dpi | **Open** — pick during implementation against a printed proof; candidates in FR-4a. |

**Questions genuinely needing the user (asked 2026-09-18, resolved above):**
rendering split (→1), app hosting (→both), power (→both + VBAT detect), alerts (→both),
HA method (→both pluggable), repo layout (→`code/`), secrets (→captive portal + BLE),
paging (→scheduled rotation), project path (→`code/`), OWM product (→both + toggle).

---

## 12. Sources and evidence

- Panel datasheet: `docs/GDEH0576T81_display.pdf` (rev 1.0, 2025-04-11, 17 pp) — geometry
  §1, FPC pinout §1.5, electrical §2, optical §3, precautions/lifetime §7.
- Controller datasheet: `code/SSD2677(Rev1.1)N_driver_ic.pdf` (Rev 1.1, Aug 2023, 19 pp)
  — command table §4.5 pp.7-11, OTP/VCOM pp.9-11, AC timing §9.1 p.15 (all TBD).
- Board schematic: `code/ESP32-M1-SCH-20260307.pdf` (Altium, 2026-05-12) — pin nets,
  VBAT divider, GT30 "(Reserve)" annotation.
- Vendor demo: `code/GDEH0576T81_Arduino_demo_code/` — init sequence, 1 bpp 78,200-byte
  image arrays, temperature LUT selection, sleep discipline.
- Mechanical reconstruction + accuracy caveats: `GoodDisplay_ESP32_M1_RESEARCH*.md`,
  `GoodDisplay_ESP32_M1_reconstructed_v2/`.
- Framework evidence (§9.1):
  - Arduino-ESP32 TLS stack-overflow reports: `espressif/arduino-esp32` issues
    **#566, #1025, #1260, #211**.
  - PlatformIO Arduino-core-3.x support gap: `platformio/platform-espressif32`
    issue **#1225**; community fork `pioarduino/platform-espressif32` (Arduino 3.3.11 /
    ESP-IDF 5.5.5).
  - PlatformIO Espressif32 docs — `framework = arduino | espidf`, and Arduino-as-component.
  - ESP BLE Provisioning app listings (App Store / Google Play) — "BLE based Wi-Fi
    Provisioning from IDF v3.2 and later".
- **Still outstanding (§§ 4.2, 6, 11 Q1/Q2/Q3/Q5):** web-app framework, font strategy,
  config file format, OpenWeatherMap / HA REST-vs-MQTT specifics, bitmap-transfer
  mechanism.

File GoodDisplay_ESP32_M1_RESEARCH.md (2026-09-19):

# Good Display ESP32-M1 — mechanical reconstruction for enclosure design

## Deliverables
- `GoodDisplay_ESP32_M1_mechanical.step`: multi-body STEP assembly for direct import into FreeCAD.
- `GoodDisplay_ESP32_M1_FreeCAD.FCMacro`: native FreeCAD macro that creates named Part solids plus case-clearance helpers.
- `GoodDisplay_ESP32_M1_locations.csv`: editable mechanical location table.
- `GoodDisplay_ESP32_M1_board_outline.dxf`: board outline for sketches / enclosure workflows.

## Coordinate system
Origin is the **bottom-left PCB corner when viewing the component side straight-on**. X goes right (0–48 mm), Y goes up (0–66 mm), and Z=0 is the PCB bottom. The official site writes the outside dimensions as **66 × 48 × 1.0 mm**; the model represents that as 48 mm X × 66 mm Y × 1.0 mm Z.

## Sourced facts
Good Display's current ESP32-M1 product page specifies:
- Outside dimensions: 66 × 48 × 1.0 mm.
- USB Type-C power/data.
- 3.7 V Li-ion battery connector, SH1.0.
- Power switch.
- microSD slot.
- User button.
- Brightness adjustment resistor (RT).
- Front-light voltage select and HV switch.
- Front-light FPC.
- e-Paper FPC, P5, 24-pin.
- Touch FPCs, P6/P7.
- RESE resistor-match switch, P4.
- RST and BOOT buttons.
- ESP32-WROOM-32D module.

Espressif's ESP32-WROOM-32D datasheet specifies the module at **18.00 × 25.50 × 3.10 mm** (nominal, with dimensional tolerances in the datasheet). That known component and the official 48 × 66 mm PCB were used as independent image-scale checks.

Official references:
- Good Display ESP32-M1 product page: https://www.good-display.com/product/1068.html
- Good Display ESP32-M1 schematic listing: https://www.good-display.com/companyfile/2058.html
- Espressif ESP32-WROOM-32D / 32U datasheet: https://documentation.espressif.com/esp32-wroom-32d_esp32-wroom-32u_datasheet_en.html

## What is inferred
Good Display does **not** publish a dimensioned mechanical drawing, board STEP file, or PCB layout/gerbers on the public product/download pages I found. Therefore:
- PCB **size and thickness** are sourced.
- WROOM-32D **body dimensions** are sourced.
- Connector/switch/button **identity and function** are sourced from Good Display.
- The **XY locations**, PCB corner radius, mounting-hole positions/diameters, and most peripheral component body dimensions are reconstructed from the official straight-on product photograph and standard package proportions.

The STEP/macro intentionally use simple bounding solids rather than pretending to know exact manufacturer part numbers for every connector. For a case, that is generally preferable: it exposes the wall-opening and interference geometry clearly.

## Location table summary
Dimensions below are the model values. For box solids, X/Y is lower-left. Cylinders use center X/Y.

| Item | X | Y | Size / dia | Z height | Confidence |
|---|---:|---:|---|---:|---|
| ESP32-WROOM-32D | 24.0 | 34.2 | 18.0 × 25.5 | 3.1 | High dimensions; image-derived XY |
| USB-C receptacle | -0.7 | 51.4 | 7.8 × 9.0 | 3.25 | Medium-high |
| Battery SH1.0 | 0.2 | 41.2 | 5.3 × 4.0 | 3.0 | Medium |
| Power switch body | 0.2 | 31.4 | 6.2 × 5.2 | 2.4 | Medium-high |
| Power actuator | -3.0 | 32.5 | 3.4 × 3.0 | 1.45 | Medium-high |
| microSD socket | 0.4 | 14.8 | 13.7 × 15.2 | 1.85 | Medium-high |
| User KEY | 4.6 | 7.8 | 4.6 × 4.6 | 2.4 | Medium-high |
| Brightness RT | 7.0 | 2.6 | Ø5.0 | 3.2 | Medium-high |
| P8 voltage select | 14.0 | 1.0 | 7.0 × 5.5 | 5.5 | Medium |
| SS1 HV switch | 21.0 | 5.8 | 5.4 × 3.4 | 2.4 | Medium |
| P9 front-light FPC | 22.5 | -0.2 | 7.0 × 4.2 | 2.1 | Medium-high |
| Touch P6 FPC | 29.8 | -0.2 | 8.0 × 4.2 | 2.1 | Medium |
| Touch P7 FPC | 43.6 | 25.5 | 4.6 × 8.0 | 2.2 | Medium |
| P5 24-pin e-paper FPC | 43.3 | 7.0 | 5.0 × 16.0 | 2.2 | Medium-high |
| P4 RESE body | 43.6 | 49.8 | 4.5 × 5.2 | 2.5 | Medium-high |
| P4 RESE actuator | 47.6 | 51.0 | 3.0 × 2.8 | 1.4 | Medium-high |
| RST button | 8.6 | 59.0 | 4.5 × 4.5 | 2.5 | Medium |
| BOOT button | 15.0 | 59.0 | 4.5 × 4.5 | 2.5 | Medium |
| Mounting holes | centers 3,3 and 45,63 | Ø3.2 | through | — | Medium-high |

## Enclosure use
The model includes a `Case_Clearances` group / `CLR_*` solids. These are deliberately larger than the nominal hardware and can be Boolean-subtracted from a case wall/cover. They cover USB-C, microSD card insertion, power switch access, RESE access, FPC exits, pushbutton access, and screwdriver access to the brightness trimmer.

For a one-off FDM enclosure, leave an additional **0.4–0.7 mm per side** around board-edge openings, depending on your printer/material. Do not make injection-mold tooling or a zero-clearance machined enclosure from the inferred dimensions without checking a physical board; the public information is not sufficient for that accuracy level.

## FreeCAD workflow
1. Open the STEP directly in FreeCAD for a fixed multi-body reference model; or
2. Copy `GoodDisplay_ESP32_M1_FreeCAD.FCMacro` into your FreeCAD macro directory and execute it. The macro creates named native `Part::Feature` objects and a `Case_Clearances` group.
3. Hide `Case_Clearances` for normal viewing; show it when creating wall cutouts.
4. Save the generated document as `.FCStd` after any dimension corrections measured from your actual board.

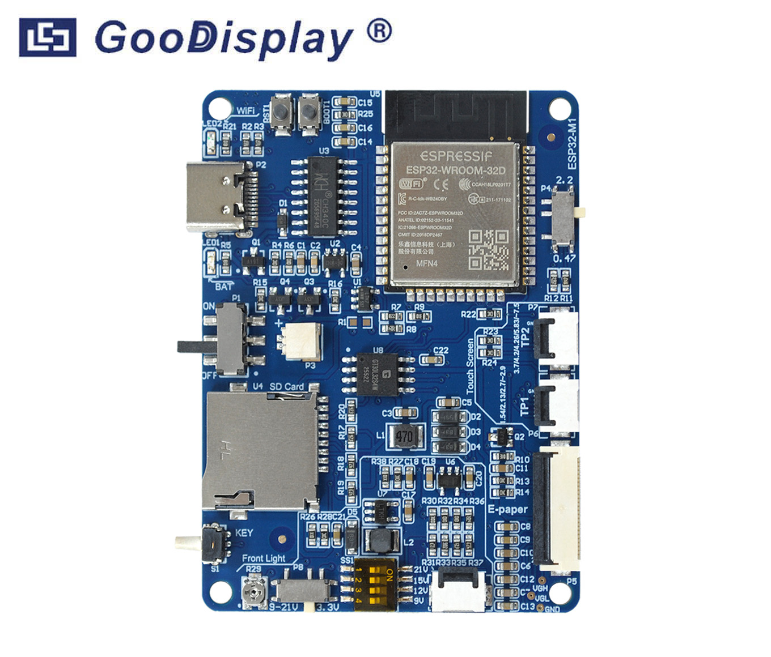
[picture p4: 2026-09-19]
docs/esp32-m1.jpg

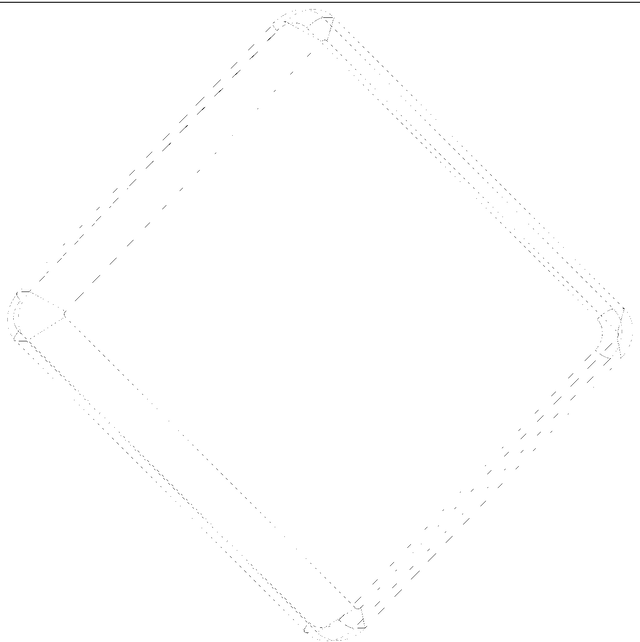
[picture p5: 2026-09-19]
work/cad/shell_iso2b.png

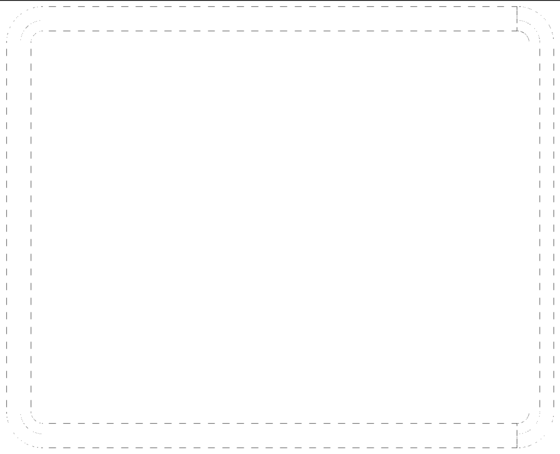
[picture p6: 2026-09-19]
work/cad/shell_front_zoom.png

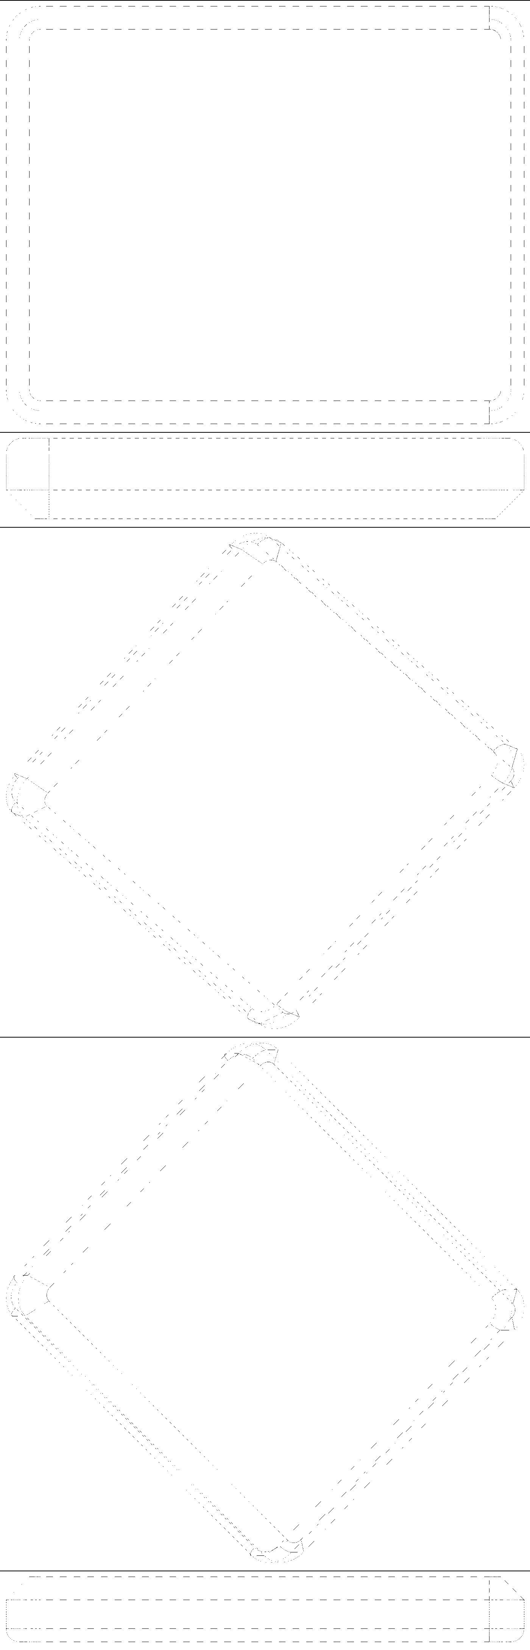
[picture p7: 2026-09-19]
work/cad/shell_views.png

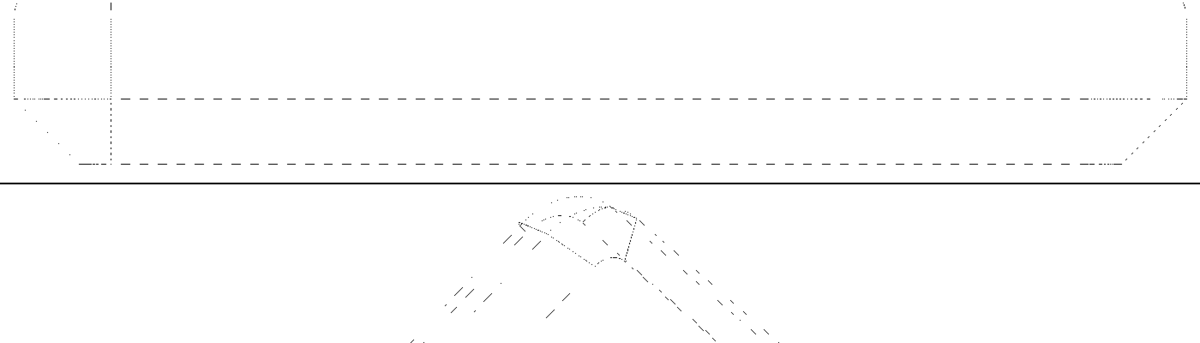
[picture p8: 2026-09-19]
work/cad/shell_side_zoom.png

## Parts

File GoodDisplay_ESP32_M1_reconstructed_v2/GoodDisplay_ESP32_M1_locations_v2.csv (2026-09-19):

ref | feature | center_x_mm | center_y_mm | width_x_mm | depth_y_mm | height_above_pcb_mm | basis
PCB | outline | 24 | 33 | 48 | 66 | 1 | published
Mount holes | 4x hole centers | 2.40/45.60 | 2.45/63.65 | 2.15 |  |  | photo-scaled
P2 | USB-C | 1.85 | 52.45 | 8.5 | 8.9 | 3.15 | photo-scaled; package envelope
RST | pushbutton | 9.9 | 63.55 | 4.0 | 4.2 | 2.3 | photo-scaled
BOOT | pushbutton | 13.75 | 63.55 | 4.0 | 4.2 | 2.3 | photo-scaled
P4 | RESE slide | 46.1 | 49.85 | 3.9 | 8.2 | 2.05 | photo-scaled
P1 | battery SH1.0 | 11.15 | 33.75 | 5.0 | 5.0 | 3.0 | photo-scaled / connector family
SW | power slide | 2.55 | 33.25 | 5.5 | 8.3 | 2.25 | photo-scaled
U4 | microSD socket | 7.25 | 20.45 | 14.6 | 15.4 | 1.75 | photo-scaled
S1 | KEY side button | 1.1 | 8.75 | 4.2 | 4.7 | 2.2 | photo-scaled
RT | brightness trimmer | 6.05 | 2.85 | 3.8 | 3.8 | 2.25 | photo-scaled
P8 | front-light voltage select | 13.0 | 2.35 | 9.1 | 3.6 | 1.8 | photo-scaled
SS1 | front-light HV DIP | 21.35 | 2.95 | 4.6 | 5.1 | 2.15 | photo-scaled
P6 | front-light FPC | 32.15 | 2.55 | 6.7 | 5.1 | 2.1 | photo-scaled
TP2 | touch FPC | 45.25 | 34.8 | 5.4 | 7.35 | 2.0 | photo-scaled
TP1 | touch FPC | 45.25 | 27.05 | 5.4 | 7.35 | 2.0 | photo-scaled
P5 | 24-pin e-paper FPC | 45.55 | 14.85 | 4.9 | 16.0 | 2.15 | photo-scaled
U5 | ESP32-WROOM-32D | 32.55 | 53.7 | 18.0 | 25.5 | 3.1 | published module size; photo-scaled XY

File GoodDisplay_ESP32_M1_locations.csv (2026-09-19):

name | x_mm | y_mm | size_x_mm | size_y_mm | z_base_mm | height_mm | geometry | access_edge | confidence | location_definition
ESP32_WROOM_32D | 24.0 | 34.2 | 18.0 | 25.5 | 1.0 | 3.1 | box | top | high | x/y lower-left for boxes; center for cylinders
USB_C_receptacle | -0.7 | 51.4 | 7.8 | 9.0 | 1.0 | 3.25 | box | left | medium-high | x/y lower-left for boxes; center for cylinders
BAT_SH1_0_2P | 0.2 | 41.2 | 5.3 | 4.0 | 1.0 | 3.0 | box | left | medium | x/y lower-left for boxes; center for cylinders
Power_switch_body | 0.2 | 31.4 | 6.2 | 5.2 | 1.0 | 2.4 | box | left | medium-high | x/y lower-left for boxes; center for cylinders
Power_switch_actuator | -3.0 | 32.5 | 3.4 | 3.0 | 1.55 | 1.45 | box | left | medium-high | x/y lower-left for boxes; center for cylinders
microSD_socket | 0.4 | 14.8 | 13.7 | 15.2 | 1.0 | 1.85 | box | left | medium-high | x/y lower-left for boxes; center for cylinders
User_KEY | 4.6 | 7.8 | 4.6 | 4.6 | 1.0 | 2.4 | box | top | medium-high | x/y lower-left for boxes; center for cylinders
Brightness_RT | 7.0 | 2.6 | 5.0 | 5.0 | 1.0 | 3.2 | cyl | bottom/top | medium-high | x/y lower-left for boxes; center for cylinders
FrontLight_voltage_select_P8 | 14.0 | 1.0 | 7.0 | 5.5 | 1.0 | 5.5 | box | bottom/top | medium | x/y lower-left for boxes; center for cylinders
FrontLight_HV_switch_SS1 | 21.0 | 5.8 | 5.4 | 3.4 | 1.0 | 2.4 | box | top | medium | x/y lower-left for boxes; center for cylinders
FrontLight_FPC_P9 | 22.5 | -0.2 | 7.0 | 4.2 | 1.0 | 2.1 | box | bottom | medium-high | x/y lower-left for boxes; center for cylinders
Touch_FPC_P6 | 29.8 | -0.2 | 8.0 | 4.2 | 1.0 | 2.1 | box | bottom | medium | x/y lower-left for boxes; center for cylinders
Touch_FPC_P7 | 43.6 | 25.5 | 4.6 | 8.0 | 1.0 | 2.2 | box | right | medium | x/y lower-left for boxes; center for cylinders
EPaper_FPC_P5 | 43.3 | 7.0 | 5.0 | 16.0 | 1.0 | 2.2 | box | right | medium-high | x/y lower-left for boxes; center for cylinders
RESE_switch_P4_body | 43.6 | 49.8 | 4.5 | 5.2 | 1.0 | 2.5 | box | right | medium-high | x/y lower-left for boxes; center for cylinders
RESE_switch_P4_actuator | 47.6 | 51.0 | 3.0 | 2.8 | 1.6 | 1.4 | box | right | medium-high | x/y lower-left for boxes; center for cylinders
RST_button | 8.6 | 59.0 | 4.5 | 4.5 | 1.0 | 2.5 | box | top | medium | x/y lower-left for boxes; center for cylinders
BOOT_button | 15.0 | 59.0 | 4.5 | 4.5 | 1.0 | 2.5 | box | top | medium | x/y lower-left for boxes; center for cylinders
WiFi_LED | 4.2 | 61.0 | 1.2 | 1.2 | 1.0 | 0.8 | cyl | top | low-medium | x/y lower-left for boxes; center for cylinders
Charge_LED | 7.4 | 46.6 | 1.2 | 1.2 | 1.0 | 0.8 | cyl | top | low-medium | x/y lower-left for boxes; center for cylinders
mounting_hole | 3.0 | 3.0 | 3.2 | 3.2 | 0 | 1.0 | cylinder | through | medium-high | x/y center
mounting_hole | 45.0 | 63.0 | 3.2 | 3.2 | 0 | 1.0 | cylinder | through | medium-high | x/y center

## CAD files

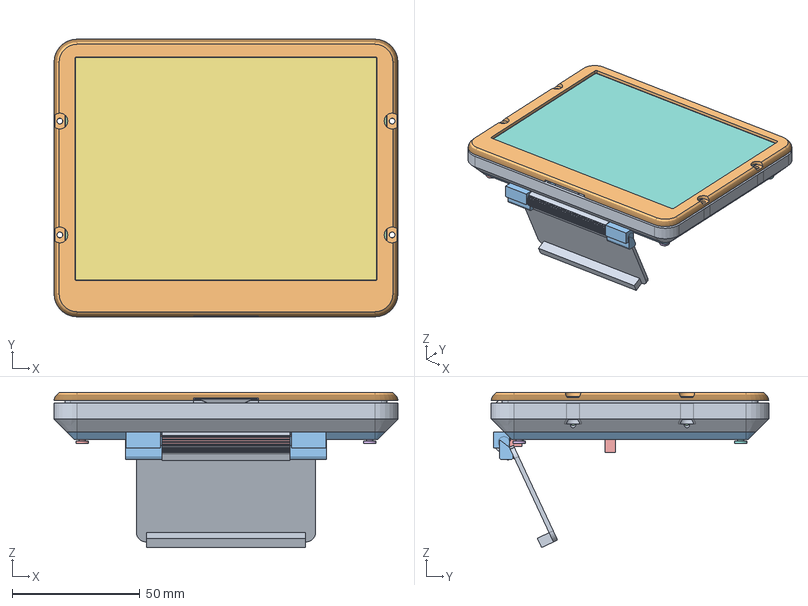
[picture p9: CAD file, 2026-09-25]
work/cad/EInk_Weather_Display_Assembly.FCStd
134.4 x 108.5 x 60.6 mm
PRINT 2: Rear electronics chassis + support grid
PRINT 1: Front retaining bezel
PRINT 3: Rear cover
PRINT 4: Connector service hatch
PRINT 5: Swing-out foot / wall-hang cover
GDEH0576T81 panel glass 125.4 x 99.5 x 0.9
Active area 117.668 x 86.972; asymmetric margins
Border 118.87 x 88.17; asymmetric margins
Panel FPC: 24 mm, direct 180-degree fold
FPC 6 mm PI stiffener
CUT: 0.5 mm rear closed-cell foam
CUT: 0.2 mm compliant front gasket ring
PCB_48x66x1
U5_ESP32_WROOM_32D
ESP32_Antenna
P2_USB_C
P2_USB_C_Port
RST_BODY
RST_ACTUATOR
BOOT_BODY
BOOT_ACTUATOR
P4_RESE_SWITCH
P4_RESE_SLIDER
P1_BAT_SH1_0
POWER_SWITCH
POWER_ACTUATOR
U4_MICRO_SD_SOCKET
MICRO_SD_ENTRY
S1_KEY
S1_KEY_ACTUATOR
RT_FRONTLIGHT_TRIMMER
RT_ADJUST_SCREW
P8_VOLTAGE_SELECT
P8_ACTUATOR
SS1_FRONTLIGHT_HV_DIP
SS1_LEVER_1
SS1_LEVER_2
SS1_LEVER_3
SS1_LEVER_4
P6_FRONTLIGHT_FPC
P6_ENTRY
TP2_TOUCH_FPC
TP2_TOUCH_FPC_ENTRY
TP1_TOUCH_FPC
TP1_TOUCH_FPC_ENTRY
P5_EPAPER_24PIN_FPC
P5_ENTRY
U3_USB_UART_SOIC
U8_MAIN_IC
L1_470
L2
Li-ion battery 70 x 39 x 11 (USER)
M3 x 8 case screw 1
M3 x 8 case screw 2
M3 x 8 case screw 3
M3 x 8 case screw 4
REFERENCE: Printed foot open 65 degrees

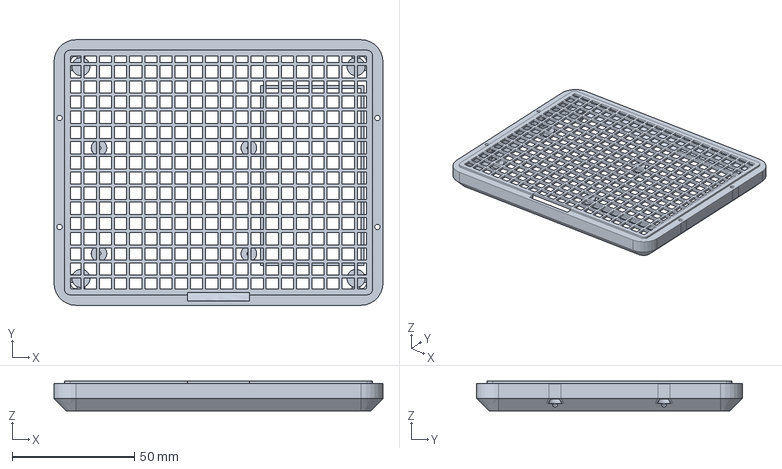
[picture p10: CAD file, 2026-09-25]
work/cad/main_chassis.FCStd
134.4 x 108.5 x 12.2 mm

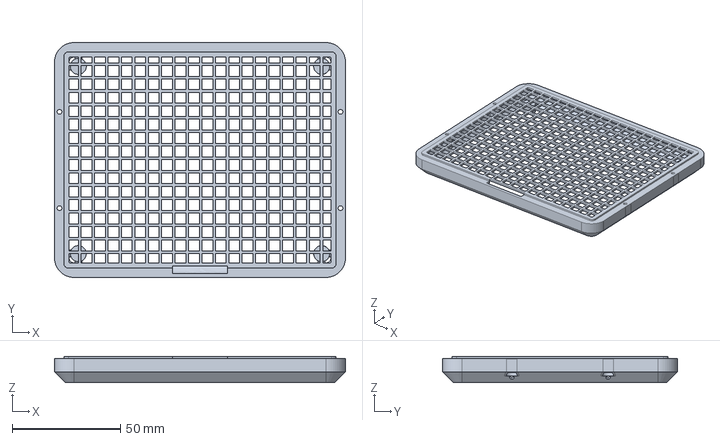
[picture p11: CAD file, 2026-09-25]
work/cad/main_chassis_base.FCStd
134.4 x 108.5 x 12.2 mm

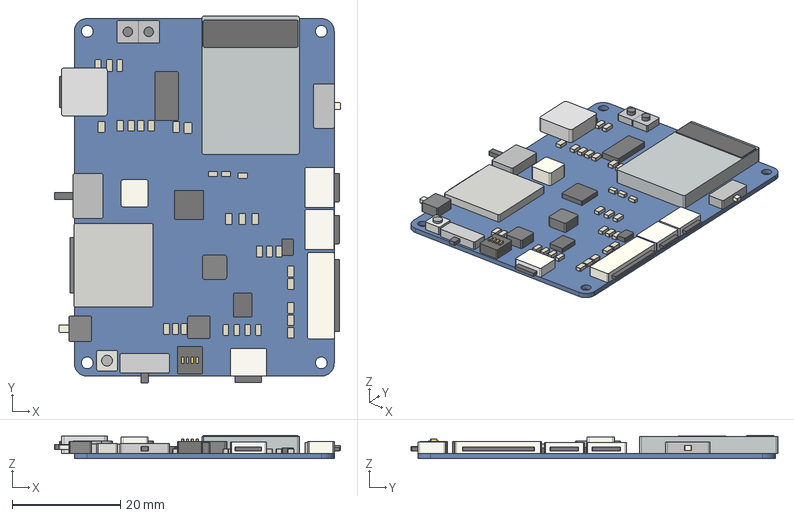
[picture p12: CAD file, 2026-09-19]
GoodDisplay_ESP32_M1_reconstructed_v2/GoodDisplay_ESP32_M1_reconstructed.step
52.8 x 67.7 x 4.31 mm
PCB_48x66x1
U5_ESP32_WROOM_32D_18x25.5x3.1
ESP32_Antenna_Area
P2_USB_C
P2_USB_C_Port
RST_SW_BODY
RST_ACTUATOR
BOOT_SW_BODY
BOOT_ACTUATOR
P4_RESE_SWITCH_BODY
P4_RESE_SLIDER
P1_BAT_SH1_0
POWER_SWITCH_BODY
POWER_SWITCH_ACTUATOR
U4_MICRO_SD_SOCKET
MICRO_SD_CARD_ENTRY
S1_KEY_BODY
S1_KEY_ACTUATOR
RT_FRONTLIGHT_TRIMMER
RT_ADJUST_SCREW
P8_VOLTAGE_SELECT_BODY
P8_VOLTAGE_SELECT_ACTUATOR
SS1_FRONTLIGHT_HV_DIP
SS1_LEVER_1
SS1_LEVER_2
SS1_LEVER_3
SS1_LEVER_4
P6_FRONTLIGHT_FPC
P6_FRONTLIGHT_FPC_CABLE_EXIT
TP2_TOUCH_FPC
TP2_TOUCH_FPC_ENTRY
TP1_TOUCH_FPC
TP1_TOUCH_FPC_ENTRY
P5_EPAPER_24PIN_FPC
P5_EPAPER_FPC_ENTRY
U3_USB_UART_SOIC
U8_MAIN_IC
L1_470_INDUCTOR
L2_INDUCTOR
U6_REGULATOR
Q2_SWITCH
PASSIVE_01
PASSIVE_02
PASSIVE_03
PASSIVE_04
PASSIVE_05
PASSIVE_06
PASSIVE_07
PASSIVE_08
PASSIVE_09
PASSIVE_10
PASSIVE_11
PASSIVE_12
PASSIVE_13
PASSIVE_14
PASSIVE_15
PASSIVE_16
PASSIVE_17
PASSIVE_18
PASSIVE_19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

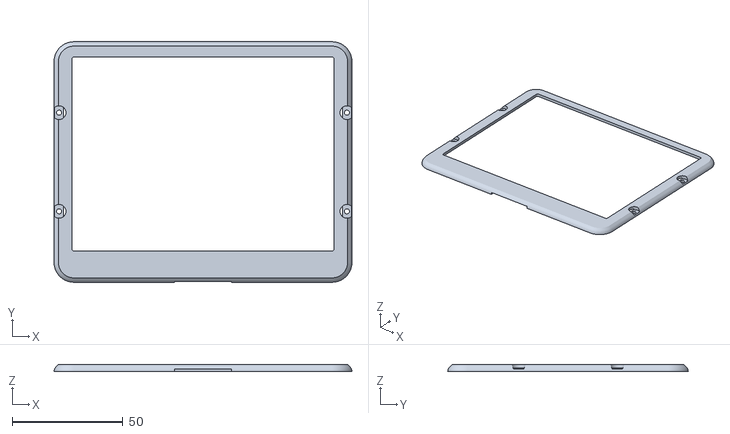
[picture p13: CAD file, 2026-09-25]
work/cad/stl/front_bezel.stl
134.4 x 108.5 x 3.20

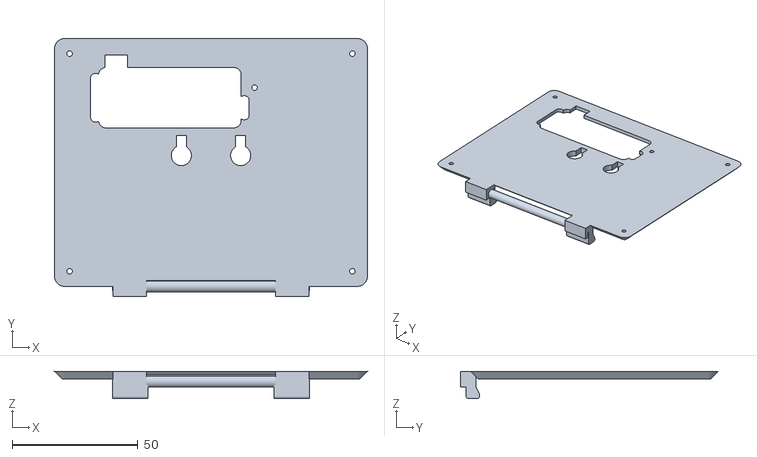
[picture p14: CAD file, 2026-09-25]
work/cad/stl/rear_cover.stl
124.4 x 102.5 x 10.8

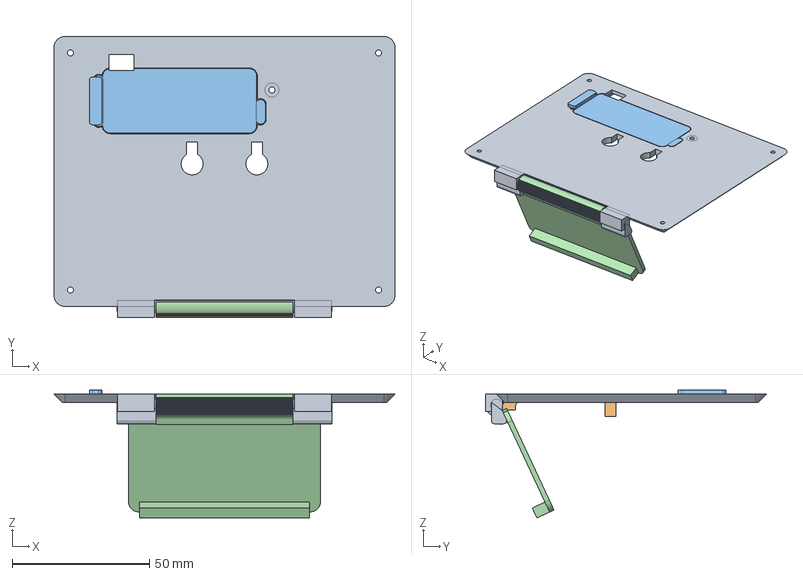
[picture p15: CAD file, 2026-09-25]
work/cad/rear_cover_foot.FCStd
124.4 x 102.5 x 46.7 mm
PRINT: Rear cover
PRINT: Swing-out foot
PRINT: Connector service hatch (snap-in)
REFERENCE: Foot open 65 degrees

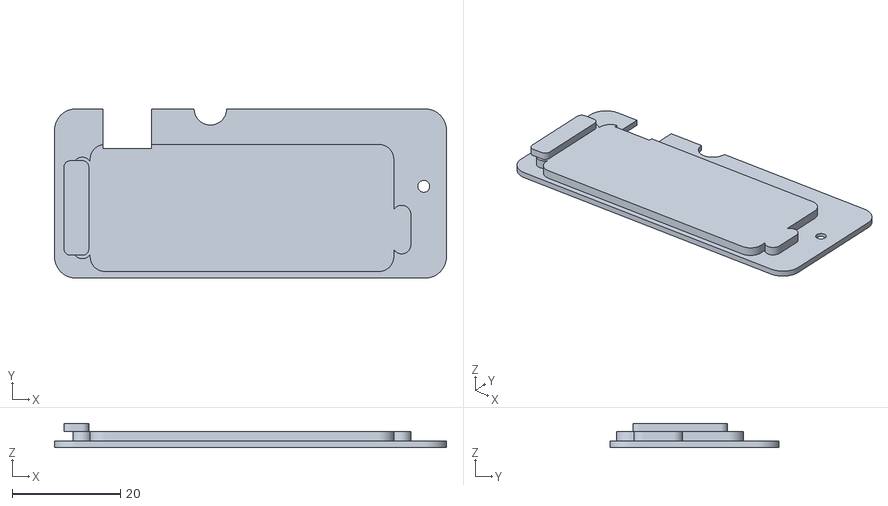
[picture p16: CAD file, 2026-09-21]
work/cad/stl/service_hatch.stl
72.5 x 31.3 x 4.50

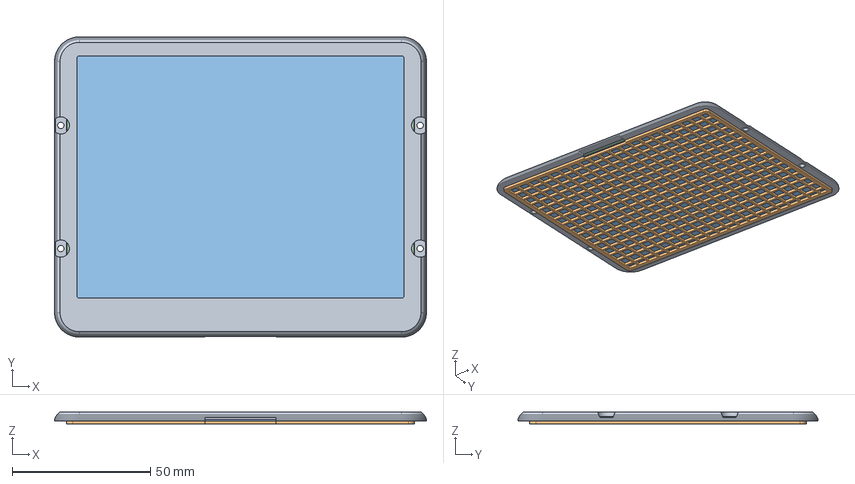
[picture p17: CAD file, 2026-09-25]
work/cad/display_capture.FCStd
134.4 x 108.5 x 4.40 mm
PRINT: Front retaining bezel
FUSE INTO CHASSIS: support grid
CUT: 0.5 mm closed-cell rear foam
CUT: 0.2 mm compliant front gasket ring

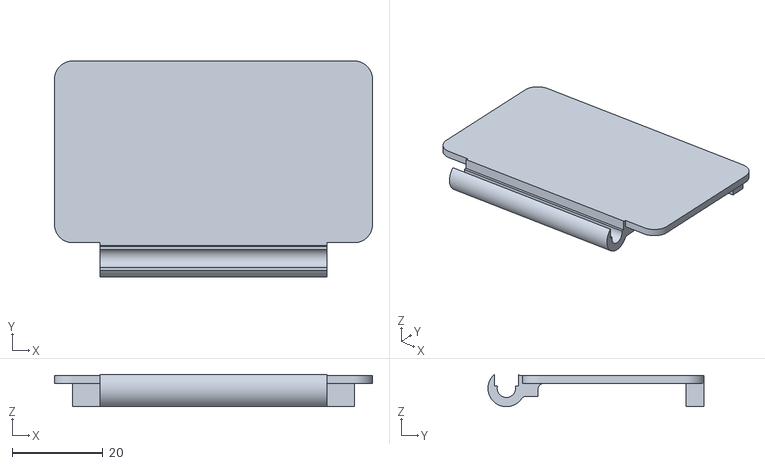
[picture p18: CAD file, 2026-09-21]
work/cad/stl/swing_foot.stl
70.0 x 47.5 x 7.13

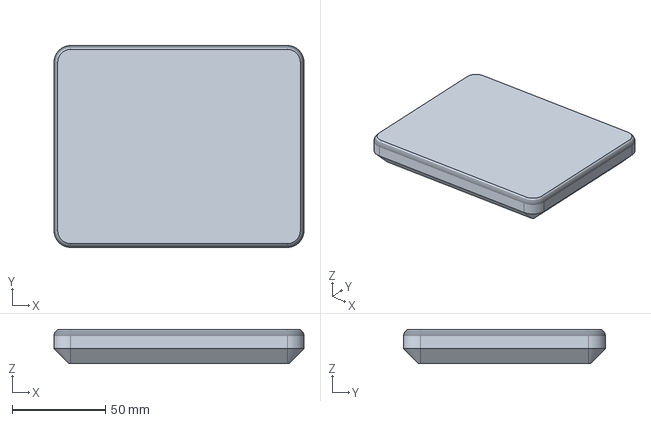
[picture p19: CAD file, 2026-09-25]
work/cad/case_shell.FCStd
134.4 x 108.5 x 18.4 mm

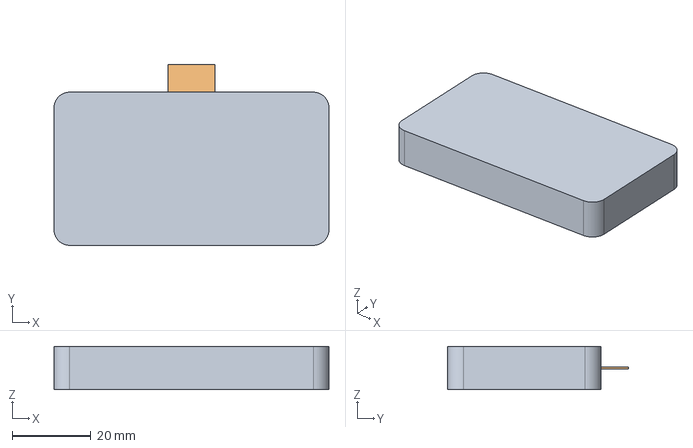
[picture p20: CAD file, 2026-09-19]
work/cad/battery.FCStd
70.0 x 46.0 x 11.0 mm
REFERENCE: Li-ion battery 70 x 39 x 11 (USER)
BATTERY_WIRE_TAB_ASSUMED

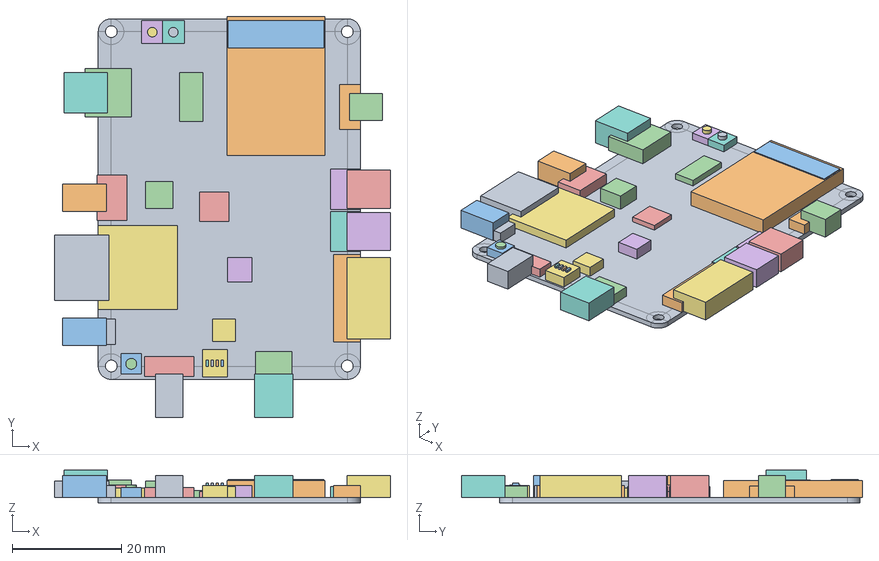
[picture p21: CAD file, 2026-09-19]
work/cad/esp32_m1.FCStd
61.5 x 73.5 x 6.00 mm
PCB_48x66x1
U5_ESP32_WROOM_32D
ESP32_Antenna
P2_USB_C
P2_USB_C_Port
RST_BODY
RST_ACTUATOR
BOOT_BODY
BOOT_ACTUATOR
P4_RESE_SWITCH
P4_RESE_SLIDER
P1_BAT_SH1_0
POWER_SWITCH
POWER_ACTUATOR
U4_MICRO_SD_SOCKET
MICRO_SD_ENTRY
S1_KEY
S1_KEY_ACTUATOR
RT_FRONTLIGHT_TRIMMER
RT_ADJUST_SCREW
P8_VOLTAGE_SELECT
P8_ACTUATOR
SS1_FRONTLIGHT_HV_DIP
SS1_LEVER_1
SS1_LEVER_2
SS1_LEVER_3
SS1_LEVER_4
P6_FRONTLIGHT_FPC
P6_ENTRY
TP2_TOUCH_FPC
TP2_TOUCH_FPC_ENTRY
TP1_TOUCH_FPC
TP1_TOUCH_FPC_ENTRY
P5_EPAPER_24PIN_FPC
P5_ENTRY
U3_USB_UART_SOIC
U8_MAIN_IC
L1_470
L2
CLR_USB_C
CLR_MICROSD
CLR_POWER
CLR_KEY
CLR_RESE
CLR_TP2
CLR_TP1
CLR_P5
CLR_P6
CLR_P8

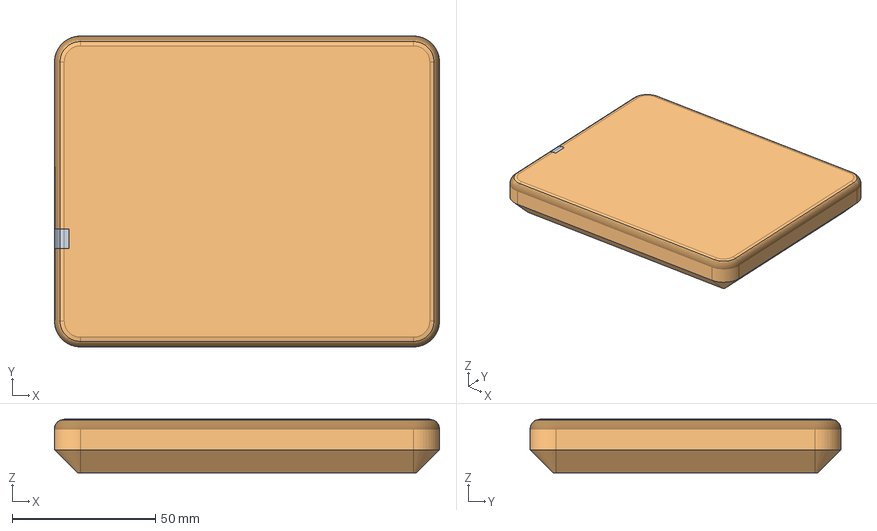
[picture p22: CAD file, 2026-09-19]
work/cad/case_body.FCStd
134.4 x 108.5 x 18.7 mm
CASE_SHELL
CASE_BODY

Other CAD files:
work/cad/stl/rear_chassis.stl
work/cad/front_frame.FCStd
work/cad/panel.FCStd
work/cad/stl/main_chassis.stl

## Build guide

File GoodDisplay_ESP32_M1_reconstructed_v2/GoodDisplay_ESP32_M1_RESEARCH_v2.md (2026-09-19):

# Good Display ESP32-M1 mechanical reconstruction v2

## Coordinate system
- Units: mm.
- Origin: lower-left PCB corner when looking at the component side, with the USB-C on the left and the ESP32 module toward the upper-right.
- +X right, +Y up, +Z away from the component side.

## Authoritative dimensions
- Good Display publishes the ESP32-M1 outside dimension as **66 × 48 × 1.0 mm**. In this model it is represented as X=48, Y=66, Z=1.0.
- Espressif publishes the ESP32-WROOM-32D envelope as **18 × 25.5 × 3.1 mm**. The module placement is photo-scaled, but its envelope is authoritative.

## Reconstruction method
The official straight-on product image is essentially orthographic. The PCB edge was used to map pixels to 48 × 66 mm independently in X and Y. The ESP32-WROOM-32D outline was then used as a scale sanity check; its photo footprint agrees with 18 × 25.5 mm closely enough to support sub-mm placement work for the large interfaces.

The model specifically reconstructs all enclosure-relevant hardware visible in the official image:
- four mounting holes
- P2 USB-C receptacle and port direction
- RST and BOOT pushbuttons
- P4 RESE slide switch and actuator direction
- P1 SH1.0 battery connector
- left-edge ON/OFF slide switch and actuator
- U4 microSD socket and card insertion direction
- S1 KEY side button
- RT front-light brightness trimmer
- P8 front-light voltage selector
- SS1 front-light HV DIP switch
- P6 front-light FPC
- TP1 and TP2 touch FPC connectors
- P5 24-pin e-paper FPC
- ESP32-WROOM-32D
- several major IC/inductor/passive landmarks so the model visually tracks the real board

## Accuracy / limitations
Good Display does not publish the PCB Gerbers, a dimensioned mechanical drawing, or an ESP32-M1 STEP file on the product page. Therefore the board outer size and WROOM module size are sourced dimensions, while mounting-hole diameter/centers and the peripheral component XY envelopes are image-derived. The official schematic identifies functions and reference designators but does not provide mechanical footprints.

For enclosure work, the large edge components are reconstructed directly from the straight-on photo rather than from generic guessed board positions. Expect image-derived XY uncertainty on the order of roughly 0.3–0.8 mm, depending on edge definition. Before committing to a tight molded enclosure, verify critical opening dimensions against a physical board. For a 3D-printed case with ~0.5–1.0 mm clearance, this reconstruction is intended to be directly useful.

## Files
- `GoodDisplay_ESP32_M1_reconstructed.step` — multi-part STEP assembly.
- `GoodDisplay_ESP32_M1_reconstructed.FCMacro` — creates native named FreeCAD objects and hidden enclosure keep-out solids.
- `GoodDisplay_ESP32_M1_locations_v2.csv` — XY envelopes and basis for all case-relevant components.
- `GoodDisplay_ESP32_M1_v2_preview.png` — top-view placement check.

## FreeCAD use
Open FreeCAD, choose **Macro → Macros → Create**, paste/import the `.FCMacro`, then run it. The generated document contains named solids. The `CASE_KEEPOUTS` group contains hidden clearance volumes for edge cutouts; toggle visibility and use Boolean Cut against your enclosure shell.

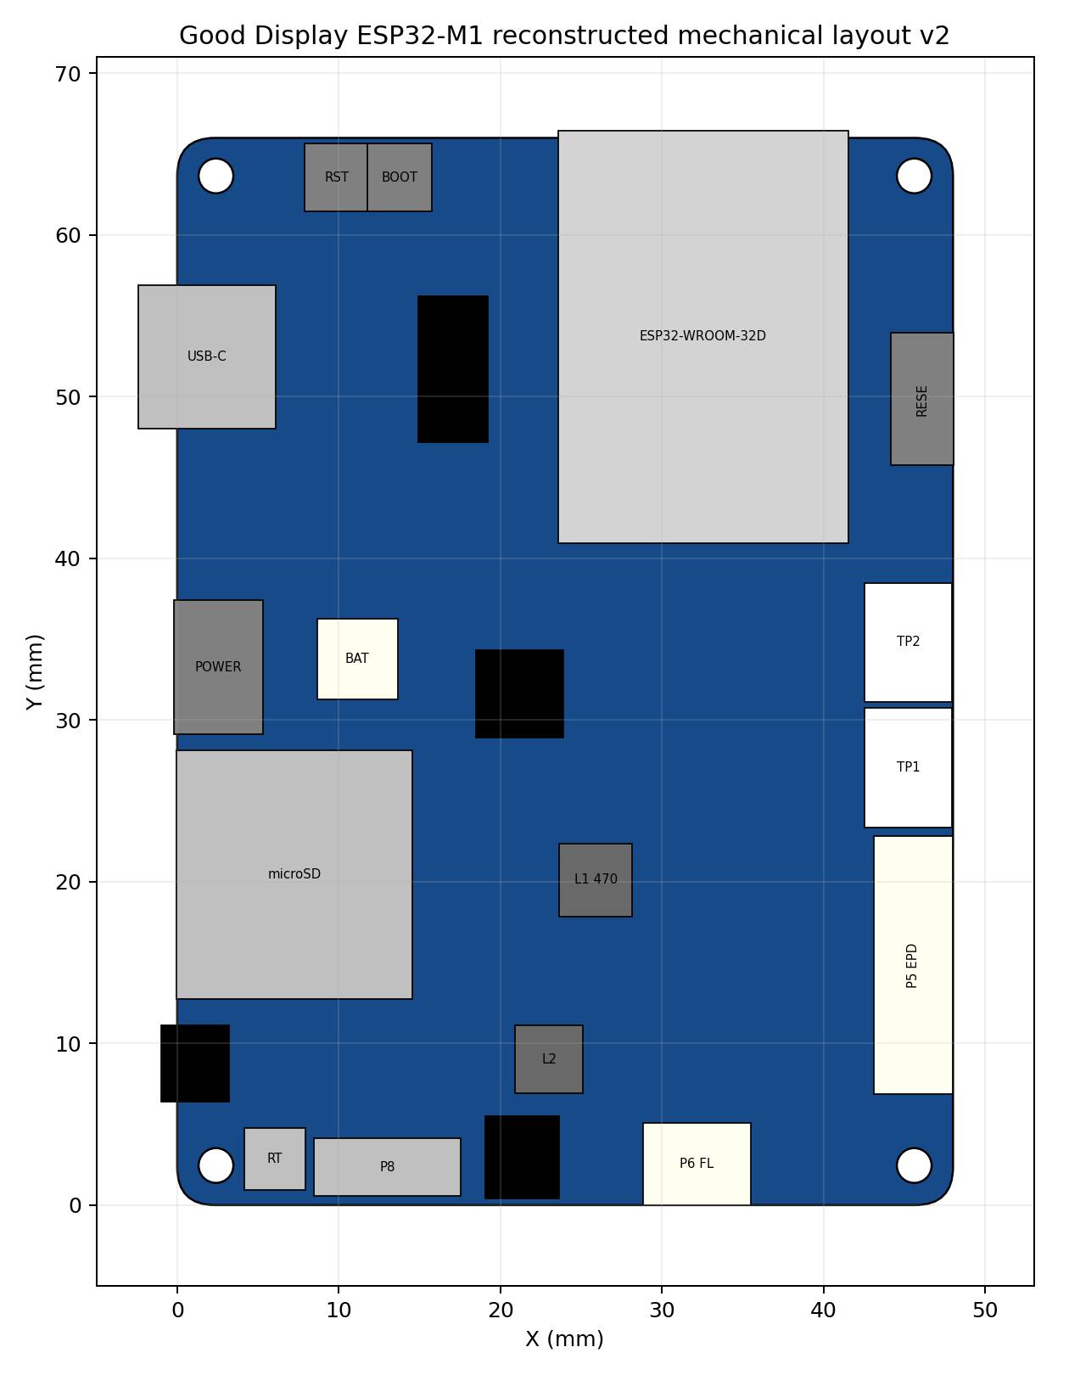
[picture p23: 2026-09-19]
GoodDisplay_ESP32_M1_reconstructed_v2/GoodDisplay_ESP32_M1_v2_preview.png

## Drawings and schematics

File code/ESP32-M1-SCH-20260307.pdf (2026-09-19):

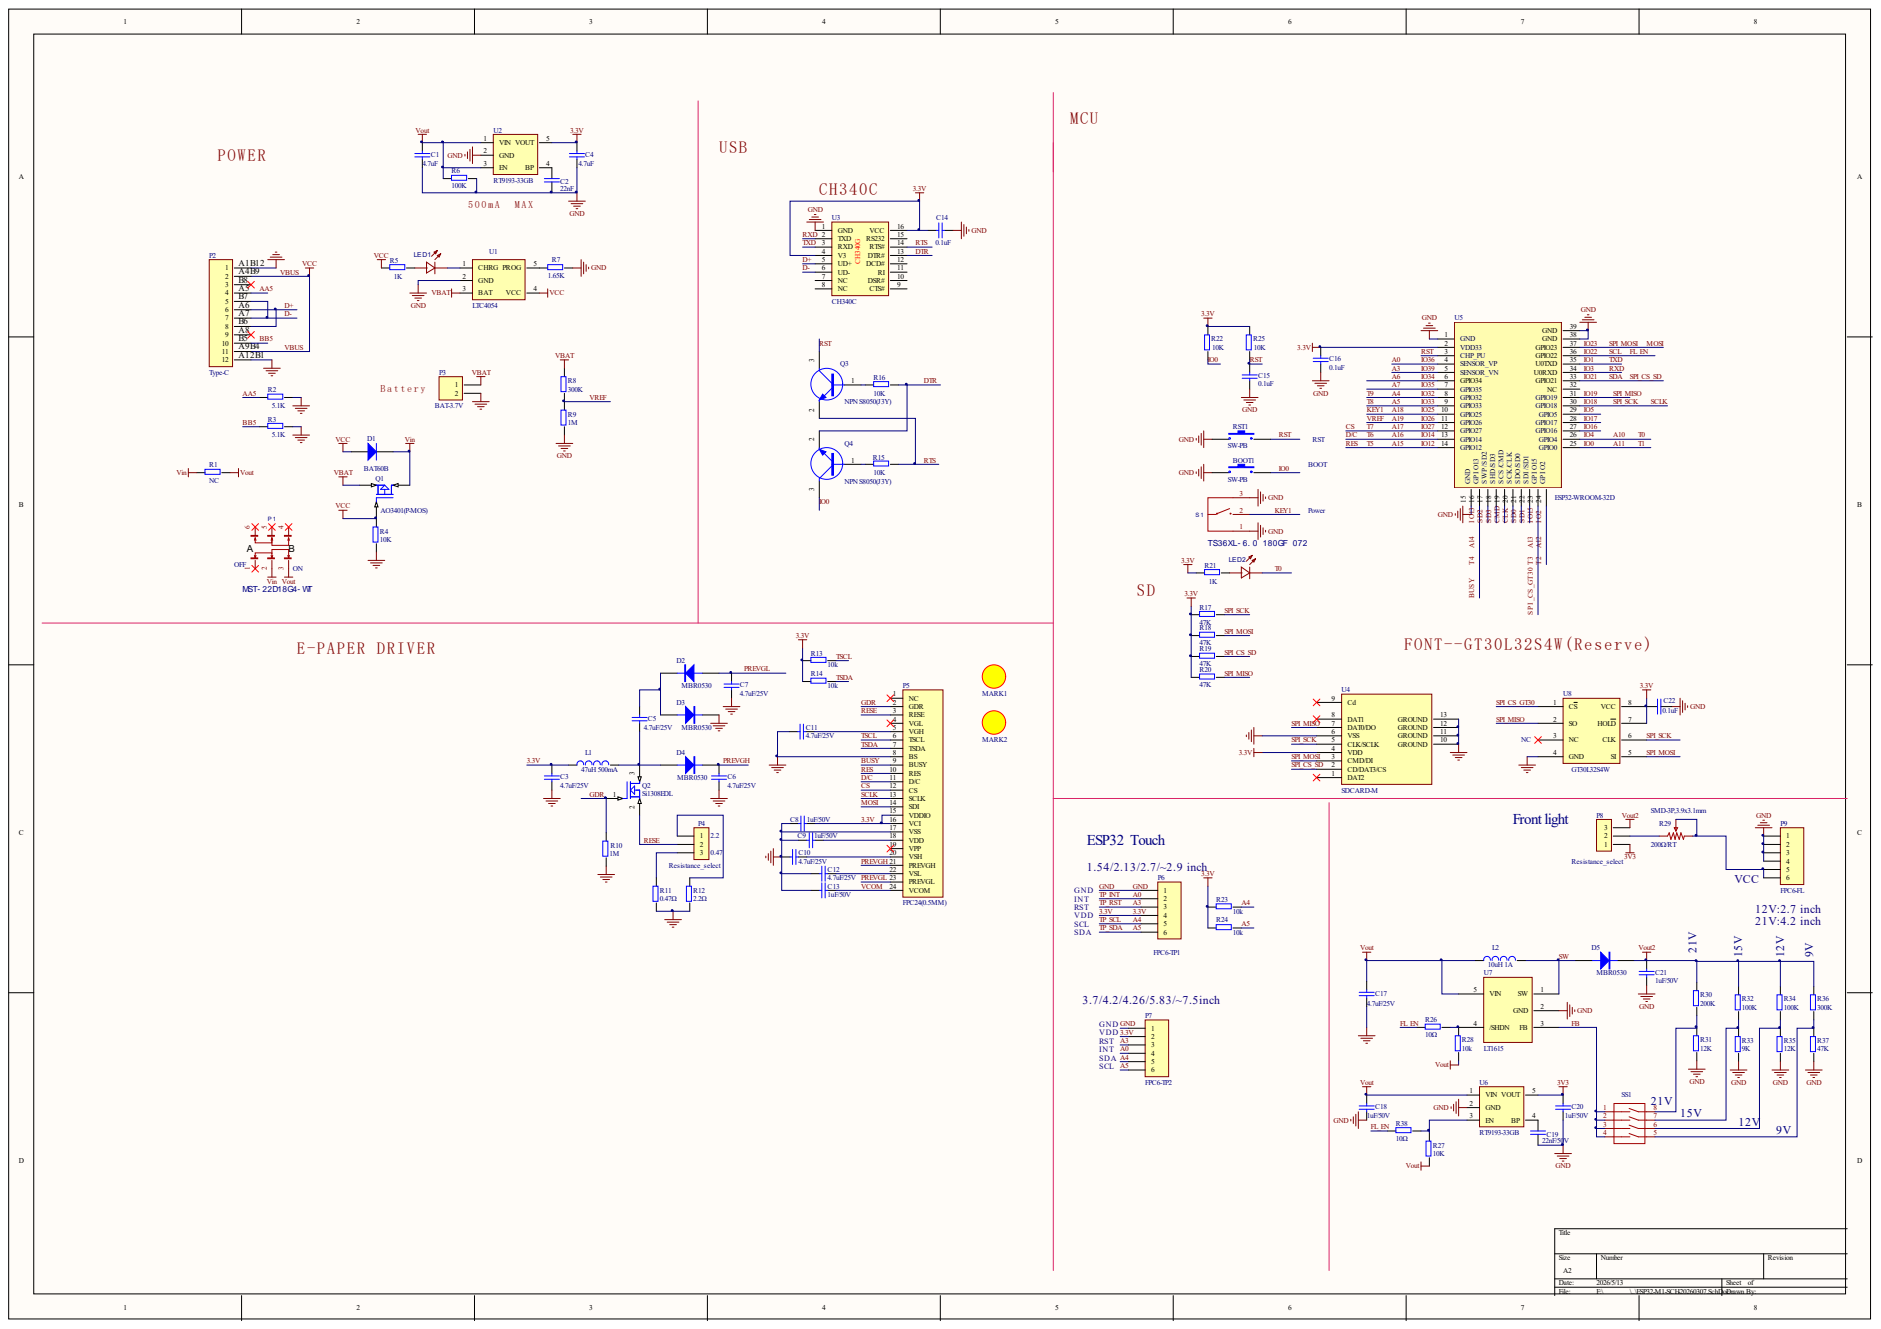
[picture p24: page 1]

5 | VIN SW GND / SHDN FB

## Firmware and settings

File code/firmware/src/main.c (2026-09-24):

#include "app_boot.h"
#include "app_refresh.h"
#include "api.h"
#include "esp_log.h"
#include "esp_system.h"
#include "freertos/FreeRTOS.h"
#include "freertos/task.h"

/* Bench verification only. Generated per-machine by tools/gen_secrets_header.py from
 * code/.env and gitignored; a normal clone has no such header, so this block does not
 * exist and the device waits to be provisioned (FR-30). */
#if __has_include("secrets_build.h")
#include "secrets_build.h"
#define HAVE_BENCH_SECRETS 1
#endif

static const char *TAG = "main";

/* Thin adapters: app_fetch_pause() returns whether a layer was held, which the API does not
 * need, and casting a function pointer across return types is undefined behaviour even where it
 * happens to work on this ABI. */
static void fetch_pause(void) { (void)app_fetch_pause(); }
static void fetch_resume(void) { app_fetch_resume(); }

/* app_main runs on the IDF main task, whose stack is CONFIG_ESP_MAIN_TASK_STACK_SIZE =
 * 3584 bytes on this board. The boot path does a TLS handshake (net_http.c), an OTA, an
 * NVS write and a 4 KB body parse — the Arduino loopTask overflow at ~8 KB is the exact
 * crash class this project exists to avoid (spec §9.1). So the work runs on a SIZED worker
 * task and app_main only starts it and returns; IDF keeps the main task alive afterwards.
 *
 * 16 KB, not NET_TLS_TASK_STACK (=8 KB): the boot path's deepest frame is that handshake
 * PLUS everything else boot does around it, and this task lives for the whole session rather
 * than only the request. net_http.h sized the worker from a measured high-water mark (3.5 KB
 * worst case); this task has no such measurement, so it keeps the handshake-era figure. */
#define APP_TASK_STACK 16384
#define APP_TASK_PRIO  5

static void app_task(void *arg)
{
    (void)arg;
#ifdef HAVE_BENCH_SECRETS
    /* Seed before the boot path reads NVS for credentials. Never overwrites (see
     * app_seed_wifi), so a provisioned device is unaffected. */
    app_seed_wifi(NET_VERIFY_SSID, NET_VERIFY_PASS);
    app_seed_owm_key(NET_VERIFY_OWM_KEY);
    /* Home Assistant is optional: an empty .env value compiles to "" and this no-ops. */
    app_seed_ha(NET_VERIFY_HA_URL, NET_VERIFY_HA_TOKEN);
#endif
    /* Give the API component a way to release the render layer's DRAM around its own TLS
     * fetches (the OTA endpoints). It cannot call into `app` itself — `app` REQUIRES `api`, so
     * that would be a dependency cycle — and without this the OTA handshake fails with
     * ALLOC_FAILED, because the render task holds the one contiguous region it needs. See
     * api_set_fetch_pause() and app_fetch_pause(). Registered before api_start(), which is the
     * only thing that reads it. */
    api_set_fetch_pause(fetch_pause, fetch_resume);
    app_boot_run();
    /* app_boot_run() returns only on USB power, where the device must stay awake to serve
     * the API. The task parks rather than exiting: a FreeRTOS task that returns from its
     * entry point aborts unless it deletes itself first, and deleting the task that owns
     * the boot path's local state is not worth the saving on a device that is mains-
     * powered in this branch. */
    for (;;) vTaskDelay(pdMS_TO_TICKS(10000));
}

void app_main(void)
{
    ESP_LOGI(TAG, "e-ink weather display starting");

    /* BEFORE the worker task, and before anything else allocates: the two framebuffers need
     * one contiguous 76.4 KiB block each, and this part has no PSRAM. Creating a 16 KiB task
     * first splits the only region large enough for the second one, which makes the render
     * path fail permanently with a misleading "out of memory" while 199 KB is still free.
     * See app_fbs_reserve() for the full explanation. */
    if (app_fbs_reserve() != ESP_OK) {
        /* Not fatal: the device still boots, serves the API and can be provisioned — it just
         * cannot draw. Restarting would loop forever against the same constraint, so this is
         * reported and the boot continues. */
        ESP_LOGE(TAG, "framebuffers unavailable; the panel cannot be updated this boot");
    }

    BaseType_t ok = xTaskCreate(app_task, "app", APP_TASK_STACK, NULL, APP_TASK_PRIO, NULL);
    if (ok != pdPASS) {
        /* Without this the device would sit in app_main doing nothing, which looks exactly
         * like a hang. Say so loudly and restart into a clean state instead. */
        ESP_LOGE(TAG, "cannot create app task (%d bytes)", APP_TASK_STACK);
        esp_restart();
    }
}

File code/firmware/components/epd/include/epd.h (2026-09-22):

#pragma once
#include <stdint.h>
#include "esp_err.h"

/* Pin map verified from the schematic (HW-2 / spec §2.3). BUSY/RES/DC/CS are Arduino
 * ANALOG aliases on the sheet (A14/A15/A16/A17) but are ordinary GPIOs. */
#define EPD_PIN_BUSY  13
#define EPD_PIN_RES   12
#define EPD_PIN_DC    14
#define EPD_PIN_CS    27
#define EPD_PIN_SCLK  18
#define EPD_PIN_SDI   23

/* Every hardware entry point returns esp_err_t. BUSY waits are BOUNDED (see epd.c):
 * ESP_ERR_TIMEOUT means the panel did not release BUSY in time — a loose FPC, an
 * unpowered panel, or a stalled controller. Callers must surface this and keep the
 * last good image (FR-29); they must never spin forever. */
esp_err_t epd_init(void);                                  /* full-update init (HW-5) */
esp_err_t epd_init_partial(void);                          /* partial-OTP init */

/* Load the waveform that matches the WIRE FORMAT `partial` selects, re-initialising only when the
 * controller is not already holding the right one. Returns ESP_OK when the correct waveform is
 * loaded.
 *
 * WHY THIS EXISTS AS ITS OWN CALL: the two waveforms are not interchangeable, and driving the
 * controller in one mode while sending the other mode's byte stream is SILENT — the panel accepts
 * the bytes and shows the wrong thing (grey, half-transitioned pixels where a value changed).
 * Whether the right one is loaded depends on history: epd_init() loads the temperature LUT ladder,
 * epd_init_partial() loads the partial OTP, and epd_wake() re-loads the full ladder ONLY when the
 * panel was successfully put to sleep. So a FAILED epd_sleep() (a BUSY timeout, which the driver
 * deliberately reports rather than retrying forever) leaves the partial OTP loaded and the panel
 * awake — and the next tick, if the policy asks for a full refresh, would then draw a full frame
 * with the partial waveform.
 *
 * Tracking the loaded waveform here rather than at the call site is what makes that unreachable:
 * the driver owns the register state, so it is the only place that can know it. `partial` selects
 * which, matching the `partial` flag of epd_write_frame_banded(). */
esp_err_t epd_ensure_waveform(int partial);

esp_err_t epd_write_frame(const uint8_t *fb1bpp);          /* full update */
/* Partial update takes the frame CURRENTLY ON THE GLASS plus the new frame; the
 * controller derives each pixel's transition from the pair (vendor PIC_display_Part_ALL). */
esp_err_t epd_write_frame_partial(const uint8_t *prev1bpp, const uint8_t *next1bpp);

/* ---- banded update: full AND partial ----
 *
 * WHY THIS EXISTS: the pair-taking call above needs BOTH whole frames resident, and this part
 * cannot hold two 78,200-byte framebuffers at once (measured: the only region large enough for one
 * is 113,840 bytes; the pair needs 156,400). Measured on the bench, the second buffer therefore
 * failed to allocate on EVERY refresh and `/api/status` showed partials_since_full: 0 against
 * fulls_total: 6 — FR-11's partial path never ran, and every refresh was a full panel flash.
 *
 * The banded writer streams the panel in horizontal bands instead, so the caller holds ONE full
 * buffer (the static layer) plus two small band buffers, whatever the refresh kind. That is what
 * makes a partial possible at all on this part.
 *
 * The caller supplies a band provider rather than frames:
 *
 *   fill(ctx, band_index, prev_out, next_out, rows_out)
 *
 * writes the band's rows into the buffers and reports how many rows it produced. Bands are
 * requested in DESCENDING index order (the panel scans bottom-up, so the first rows sent are the
 * last natural rows) and each exactly once — a provider that assumes ascending order will produce
 * a vertically scrambled panel.
 *
 * `partial` selects the wire format the controller expects: a partial interleaves the previous and
 * the next frame because the SSD2677 derives each pixel's TRANSITION from the pair, while a full
 * expands the next frame alone. The provider must still fill `next_out` for a full; `prev_out` is
 * then unused and may be ignored.
 *
 * `band_rows` MUST be > 0, and `prev_band` / `next_band` each hold band_rows * EPD_PITCH bytes.
 *
 * THE CALLER OWNS THE BAND BUFFERS, deliberately. Holding them as driver statics would make them
 * RESIDENT for the life of the device — and this part has one region large enough for the static
 * layer, so a permanently-held band pair is memory the radio cannot have at boot, which is the
 * exact starvation that stops the device being provisioned (see app_refresh.c). The app allocates
 * them for the push and frees them after, so they exist only inside the render window.
 *
 * `prev_band` may be NULL when `partial` is 0: a full update expands the next frame alone and
 * never reads the previous one. Returns ESP_OK on success. */
typedef int (*epd_band_fn)(void *ctx, int band_index, uint8_t *prev_out,
                           uint8_t *next_out, int *rows_out);

esp_err_t epd_write_frame_banded(epd_band_fn fill, void *ctx,
                                 uint8_t *prev_band, uint8_t *next_band,
                                 int band_rows, int partial);
esp_err_t epd_sleep(void);                                 /* power-off + deep sleep (FR-12) */

/* Wake the panel after epd_sleep(), which puts the CONTROLLER into deep sleep (0x07/0xA5).
 *
 * While asleep the controller ignores everything except a hardware reset, so a write issued
 * after epd_sleep() does not fail loudly — it times out on BUSY, which is indistinguishable
 * from a loose FPC. That is exactly what happened when the USB serve loop re-rendered after
 * the boot path had already slept the panel: every refresh reported ESP_ERR_TIMEOUT and the
 * display never changed.
 *
 * Cheap when the panel is already awake (returns immediately), so callers that are unsure
 * whether they slept it can call this unconditionally before drawing. */
esp_err_t epd_wake(void);
esp_err_t epd_read_temp(int *out_c);
esp_err_t epd_read_temp_hw(int *out_c);                       /* cmd 0x40, returns degC */
esp_err_t epd_wait_ready(void);                            /* bounded BUSY wait (FR-13) */
esp_err_t epd_wait_ready_ms(int timeout_ms);               /* explicit timeout */

/* Transport, used by the driver and by the BUSY regression test. */
void    epd_spi_init(void);
void    epd_spi_reset(int level);
int     epd_spi_busy_read(void);
void    epd_write_cmd(uint8_t cmd);
void    epd_write_data(uint8_t data);
void    epd_write_data_block(const uint8_t *data, int n);
int     epd_spi_read_byte(void);
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

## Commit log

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2026-09-20 feat(firmware): provisioning, captive portal, and the memory budget for both
    Task 15 (FR-30) plus the DRAM work it exposed.
    Provisioning runs BLE (wifi_prov_mgr) and a separate SoftAP captive
    portal at once, because the manager can only drive ONE scheme and a
    protocomm instance binds only one transport. Both paths converge on
    wifi_prov_mgr_configure_sta(); credentials land in NVS devcfg.
    The DNS answerer had two wire-format bugs that a hand-rolled probe could
    not catch and every real client hit: the flags field was tested without
    byte-swapping (so queries carrying the AD bit, which dig/Chrome/
    systemd-resolved all send, were dropped with no reply), and the client's
    EDNS OPT record was copi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
    [partitions.csv]
2026-09-20 feat(provisioning): show setup instructions and QR codes on the panel
    While the device is unconfigured the panel now shows the AP/BLE name, the
    PoP, and QR codes for the setup page and both provisioning apps, instead
    of the vendor logo. Before this the only way to learn how to configure
    the device was the serial log, with the phone that needs the URL already
    in hand.
    The QR matrices are generated at build time by tools/gen_qr.py with the
    well-tested qrcode library, because all three URLs are constants (the AP
    is always 192.168.4.1). A runtime encoder would be several hundred lines
    of Reed-Solomon and masking that could only produce three known outputs;
    this removes that class of bug from th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
2026-09-20 fix(provisioning): make the official ESP BLE app work, and show the Aether mark
    THE BLE FIX. Two independent faults, both now proven fixed end to end by
    running IDF's own tools/esp_prov against the device:
    1. The BLE service UUID was left at IDF's newer default instead of the
    well-known 021a9004-0382-4aea-bff4-6b3f1c5adfb4. Clients fall back to
    that published base UUID when advertisement reads fail, so they
    searched for characteristics under a base the device was not using and
    reported "'prov-session' endpoint not found" - which the app showed as
    an indefinite spin, because the BLE connection itself succeeds. IDF's
    own example sets this UUID for exactly this reason.
    2. Th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
2026-09-20 feat(provisioning): 4 QR codes on the setup screen, and factory reset on KEY1
    The screen now carries four codes, all decoded from the rendered
    framebuffer with a real QR scanner to prove they are not just present but
    readable:
    1. BLE SETUP {"ver":"v1","name":"...","pop":"...","transport":"ble"}
    2. SETUP PAGE http://192.168.4.1/
    3. iOS APP the ESP BLE Provisioning listing
    4. ANDROID APP the same app on Play
    Code 1 is the convenient path - scanning it in the app carries the device
    name, the PoP and the transport at once. It cannot be pre-generated like
    the other three (its payload embeds this device's own name), so
    lib/qrcodegen is vendored for runtime encoding. MIT licensed, u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
2026-09-20 fix(hatch): make the USB exit an open cutout, and drop the hinge detent nubs
    The service hatch's USB cable exit was a CLOSED HOLE: its cut stopped at
    y=97.0, 1.35 mm short of the plate's +Y edge (HATCH_FLANGE_Y1 = 98.35), so
    the passage had a lip across its outer end while the cover's own opening runs
    off the bay as an open cutout. The two did not match, so the cable could not
    exit. The cut now runs past the plate edge, making it an open cutout.
    Fill probes could not see this -- a closed hole has the same 0 mm3 inside its
    own volume as an open slot. Validator 19 now probes the strip from the slot
    out past the plate edge and fails if any material survives in it.
    Also removes the hinge deten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
    [EInk_Weather_Display_Assembly.FCStd, rear_cover.stl, rear_cover_foot.FCStd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]
2026-09-20 fix(provisioning): make the official BLE app work by not advertising wifi_scan
    The official ESP BLE Provisioning app on iOS hung forever on "Sending Wi-Fi
    credentials". The device side was never at fault: creds stored, association,
    IP, WIFI_PROV_CRED_SUCCESS all fine. Instrumenting the link with a
    ble_gap_event_listener (and CONFIG_LOG_MAXIMUM_LEVEL_DEBUG for the D-level
    "disconnect; reason=N" line) gave the real cause:
    iOS negotiates supervision timeout = 720 ms (30 ms interval) on connect and
    refuses to lengthen it. A peripheral-initiated ble_gap_update_params() is
    rejected (HCI 0x2A then refused) and PPCP is ignored; the negotiated value
    stayed 720 ms with PPCP set and unset. With that t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
2026-09-20 feat(provisioning): warn on 2.4 GHz only, on both the panel and the portal
    The display's radio is 2.4 GHz-only. Selecting a 5 GHz network fails the
    association, and the device then re-enters provisioning looking, from the
    phone, exactly like a wrong password -- a mistake the user cannot diagnose
    from the rest of the setup page.
    Both surfaces now say so, in the boldest form each supports:
    - Panel (lib/provscreen): a boxed, 2x callout "WARNING! / 2.4 GHz WiFi only"
    placed in the blank area under the QR grid. The left column already runs to
    the bottom edge, so a 2x block there clipped off the glass -- the position
    is derived from the grid's own row math, with a one-line fallback if the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
2026-09-20 feat(provisioning): network picker on the captive portal
    The portal only offered a blank SSID text field, so setup meant typing a
    network name by hand. It now scans and offers a dropdown.
    This is safe where it would not be over BLE: the portal only exists on the
    provisioning-only AP, where the device is not joined to any network and the
    main radio is otherwise idle, so a blocking scan contends with nothing.
    - GET /scan returns the networks, rssi-descending, capped at 24 and
    deduplicated by SSID (a multi-AP home otherwise lists "HomeNet2G" once per
    BSSID -- a live scan returned 16 entries for 9 names). Hidden SSIDs are
    skipped; they cannot be picked.
    - The page fills a <select> and co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
2026-09-20 feat(provisioning): support the ESP SoftAP Provisioning app, with a network list
    The official BLE app's network list is unusable (its scan drops the BLE link,
    unfixable from the device), so provisioning over BLE is manual-entry-only. The
    official ESP SoftAP Provisioning app has no such problem -- it talks HTTP, so
    there is no BLE link to drop -- and it CAN list networks.
    wifi_prov_setup() takes exactly one scheme and a protocomm instance carries
    exactly one transport, so the manager drives BLE and nothing else. Rather than
    run a second manager (which would fight over the Wi-Fi driver), this builds a
    SECOND protocomm instance over the portal's existing HTTP server and registers
    the manager's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
2026-09-20 fix(provisioning): make the setup QR work with the ESP SoftAP app
    The QR codes did nothing in the ESP SoftAP app: scanning gave "no device",
    and the manual device list was empty. Both had the same root cause and one
    of them cannot be fixed from our side.
    1. The payload said "transport":"ble". The SoftAP app only accepts a code
    whose transport is "softap", so it silently ignored ours. It now emits
    {"ver":"v1","name":"<AP SSID>","pop":"<PoP>","transport":"softap","security":1}
    "security" is mandatory to state: Espressif's table says an absent value is
    "considered Sec2", and this device is Sec1 -- omitting it makes the app do a
    Sec2 handshake against a Sec1 device, which fai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
2026-09-20 feat(location): map picker with two-way-synced lat/lon fields (FR-24)
    The device could guess its position from its public IP, but there was no way
    to correct it to the actual spot — and the config document's `location` field
    was parsed by nothing on the device, so a pin placed on a map would have been
    saved, echoed back, and then silently ignored. The fetch path reads only the
    NVS lat/lon blobs.
    Firmware: PUT /api/config now persists the document's location through the
    one extra-config writer, and GET /api/config injects the stored value into the
    reply. So the document is the input and the blobs stay the source of truth —
    which also means the app sees the device's own IP-derived guess i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
2026-09-20 feat(api): optional bearer-token auth for mutating endpoints (FR-31)
    Off by default, as asked — the device is meant for a trusted network and the
    config app is same-origin with the API, so requiring a token to configure a
    device would be a worse first-run than the exposure it prevents. The owner
    ticks a box in the config app to turn it on.
    It exists because POST /api/ota takes a CLIENT-SUPPLIED url and installs
    firmware from it, so ungated it is a remote firmware-replacement endpoint with
    no password — a takeover, not a leak. PUT /api/config, POST /api/bitmap and
    POST /api/refresh are gated too; reads stay open so the app can draw itself
    before a token is entered.
    Three things that mak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
2026-09-20 feat(power): make the FR-8 powerMode override actually work
    The config field, the spec and the plan all described a user override for the
    VBAT inference, but no code read it — so a USB-powered device whose owner chose
    'battery' would save the setting and carry on serving the API. Setting a field
    that the firmware ignores is the same saved-but-ignored trap this session has
    already fixed twice.
    The override is applied where the spec puts it (before WiFi init, with the
    radio off — the ADC read requires that), and a change to it now RESTARTS the
    device, because a USB device sits in the never-returning serve loop and would
    otherwise never re-read it. Verified on hardware:
    vbat=4.29V sourc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
2026-09-20 feat(webapp): canvas editor with drag, resize, snap and panel clamping (Task 18, FR-20/21)
    The preview draws the REAL framebuffer from renderPage(), painted as ImageData
    at panel resolution and CSS-scaled with image-rendering:pixelated. An HTML
    mockup would look right while the actual 1 bpp output had a clipped glyph, and
    the user would only find that out from the glass. Selection outlines and
    handles are drawn on TOP, never into the framebuffer, so a selected widget
    still looks exactly like it will print.
    Drag snaps the leading AND trailing edge against panel edges and other widgets.
    Snapping only the left edge would make right-edge alignment impossible, which is
    the alignment a right-just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
2026-09-20 fix(render): the degree sign had no glyph, blanking every °F temperature
    THE BUG: the font atlases covered only printable ASCII (0x20-0x7E), so U+00B0 had
    no glyph. font_measure() then FAILED for "68.4°F" and the renderer's rule is "no
    glyph, draw nothing" — so a temperature rendered as NOTHING on the panel. Not a
    missing unit mark: a blank field. Imperial temperatures, the primary use case,
    were simply broken, and the failure was silent by construction.
    Found by rendering the default layout and noticing the value box was empty:
    the placeholder "--" only rendered because °F was appended to it, which made the
    whole string unmeasurable and took the dashes down with it.
    THE FIX, in the t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
2026-09-20 feat(webapp): data binding, formatting, alert rules and the property inspector (Task 19)
    Alert evaluation mirrors lib/alerts/src/alerts.c case for case, because the app
    shows whether a rule fires and the device decides whether to draw the alert bar —
    a disagreement about an edge means the app says one thing and the panel another,
    with nothing to explain it. The tests are written against the C semantics: gt
    strict and gte inclusive, most-severe-wins, and the non-finite guard.
    That guard is not padding. Without it every comparison against NaN is false
    EXCEPT ne, so a "not equal to 0" rule would fire on a missing reading — an alarm
    meaning "the sensor is absent", which nobody can act on.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
2026-09-20 feat(webapp): config file save/load, chunked bitmap upload, device client (Task 20)
    Config files are download/upload JSON, not the File System Access API: MDN
    classes showSaveFilePicker() as non-Baseline and requiring a secure context,
    which rules it out for a device served over plain HTTP on a LAN IP. A newer
    schemaVersion is REFUSED rather than best-effort read (FR-26b) — the same field
    may mean something else next version, and guessing puts a wrong picture on the
    glass with no error anywhere. An OLDER file loads with its missing fields
    defaulted, so saved layouts do not expire when the schema grows.
    The bitmap chunker refuses a buffer that is not exactly 78,200 bytes. A short
    frame is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
2026-09-20 feat(webapp): default weather dashboard layout (Task 21, FR-17)
    A real landscape dashboard for the stated use case: hero current temperature,
    the two Home Assistant entities the user named, condition and wind, a
    today/tomorrow high-low strip, a full-width alert bar, and a second page so the
    rotation scheduler is exercised by default. Tests enforce the things a layout
    can get wrong invisibly: nothing off-panel, nothing overlapping (two widgets
    sharing pixels means one stamps over the other, and which wins depends on array
    order), and the hero keeps the largest type.
    ONE FACE RULE, in canvas/face.ts. The panel has exactly TWO rasterised faces —
    20 px body and 64 px value (FR-4a: a 1 bpp pan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
2026-09-20 feat(cad): beefier hinge hooks, rebuild the 65deg stop, and hook the hatch's -X end
    Hooks: CLIP_WALL 1.6 -> 2.00, CLIP_W 3.0 -> 4.50. The ring's radial bending
    section modulus (CLIP_W*CLIP_WALL^2/6) goes 1.28 -> 3.00 mm3. PIN_PRELOAD
    0.12 -> 0.15, since with no detent friction is the only thing holding the leg.
    Axis lowered to -1.05 so the taller clip stays under the cover.
    Stop: the two-span buttress broke because it existed only at the case ends
    (nothing under the leg's central 53 mm), its 65deg bearing contact was 0.28 mm3
    and its weld 2.85 mm3. It is now the same buttress section repeated in EVERY
    gap between the clips -- a section under the bearing face at every x. Contact
    at 65deg is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
    [EInk_Weather_Display_Assembly.FCStd, rear_cover.stl, rear_cover_foot.FCStd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]
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2026-09-20 fix(cad): hold the leg by friction, since no stop can
    Measured, and it is why a more robust stop changed nothing: as the leg CLOSES
    its closest material moves AWAY from the cover. Leg/cover overlap is 18.68 mm3
    at every angle 0..63, unchanged, and the minimum leg-to-cover gap grows from
    0.018 mm at 65 deg to 0.155 mm folded. The only contact anywhere is the clip's
    bore preload on the pin, so a stop on the closing side is simply never reached.
    The only closure-side holds at a pivot are friction, or a bore detent -- and the
    detent was correctly rejected (a radial nub in a C-clip splays the free mouth
    lips). So the preload is raised 0.12 -> 0.18, the largest value that passes the
    pessimistic o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
    [EInk_Weather_Display_Assembly.FCStd, rear_cover.stl, rear_cover_foot.FCStd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]
2026-09-20 fix(firmware): render the pushed layout, not two hard-coded boxes
    The device never rendered a user's layout. app_refresh.c stamped a
    temperature and "--" into two fixed boxes (DEFAULT_FIELDS), while the
    document's widgets array was parsed for scheduling and thrown away. Every
    binding, forecast, Home Assistant path, alert rule and page rotation was
    host-tested but had zero production callers, so only the current
    temperature ever reached the glass — in a box the user had not authored.
    - lib/layout/widgets.{c,h}: parse widgets, bindings, format and alert rules
    from the document (the same key spellings the web app emits).
    - lib/layout/value_resolve.{c,h}: resolve each binding against the fe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
    [main.c]
2026-09-21 feat(cad): one solid hinge bearing, solid end stops, and a real hatch lip
    Hinge: the three clips are replaced by ONE centred bearing, 50 mm of the
    70 mm hinge span, as the user asked. One continuous bearing surface and one
    large weld instead of three stress concentrations. Friction is now 69.2 mm3
    of bore interference (was 18.7 over the three clips).
    Stop: with the ends of the hinge span left empty by the single bearing, the
    65deg stop becomes two SOLID BLOCKS (x 28.0..42.2 and 92.2..106.4, ~10 mm
    wide each against the previous 3.4 mm sections), merged into both end webs.
    The old stops were small only because they had to be squeezed into the gaps
    between three clips -- anywhere under a clip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
    [EInk_Weather_Display_Assembly.FCStd, rear_cover.stl, rear_cover_foot.FCStd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]
2026-09-21 fix(firmware): give per-page artwork its own flash, and stop it failing silently
    Two defects in the per-page artwork store, both of which the device reported as
    success while the panel kept its old picture — the user's "if it doesn't show on
    the device it's broken".
    1. SHARED PARTITIONS. The artwork store and the legacy bitmap store both resolved
    to bitmap_a/bitmap_b. A promote erases its spare slot before writing, so the
    two erased EACH OTHER: pushing artwork wiped the layout's static layer and the
    panel fell back to rendering widgets over the factory boot mark. The artwork
    now has its own pair (artwork_a/artwork_b) and the table still fills 0x400000
    exactly — 0xC000*2 +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
    [partitions.csv]
2026-09-21 fix(cad): narrow the hatch lip and give it a plain square tip
    The retention lip on the screw-opposite edge was 18.80 mm wide and reused
    the anti-rotation key's Y span, so it read as a continuation of the hatch
    edge rather than a tongue hooking under the cover. It now uses its own
    HATCH_LIP_Y0/Y1 (17.50 mm, inset 3.00 mm per side vs the 23.50 mm plug),
    and the 45-degree self-guiding chamfer on its tip is gone -- the staircase
    that chamfer left was the "weird shape" on the tip.
    Validator 19 now samples the lip's own footprint and asserts outright that
    it is narrower than the hatch edge, rather than testing a restated number.
    [EInk_Weather_Display_Assembly.FCStd, rear_cover_foot.FCStd, service_hatch.stl]
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2026-09-21 fix(cad): anchor the hinge pin along its length, not at two 3.8 mm webs
    The pin is 78.00 mm long but only 3.80 mm was welded at each end, leaving
    10.20 mm cantilevered per side between the web and the bearing. Sweeping the
    foot over the full swing showed the free room ran right up to the sweep
    cavity wall, so the webs now do too: 3.80 -> 13.00 mm welded per end, 147 ->
    327 mm3 of fused material, and the unsupported span falls to 0.60 mm.
    The cavity wall is the hard limit and it is real -- past it the bearing
    collides with the anchor (14.39 mm3 at 43.0 mm, 90 deg), which is why the
    middle stays open. New validator 40 guards all three properties: the webs
    reach the wall, the anchor is never t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
    [EInk_Weather_Display_Assembly.FCStd, rear_cover.stl, rear_cover_foot.FCStd]
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2026-09-21 feat(cad): recess the service hatch flush into the rear cover
    The hatch plate stood 1.2 mm proud of the cover's rear face. The cover's
    rear face is now cut away over the plate's outline (HATCH_RECESS_T deep,
    HATCH_RECESS_CLEAR per side) and the plate drops into it, finishing flush.
    The lip the user asked to keep is the 1.80 mm of cover left beneath the
    seat, running all the way round the plate -- verified at 11 stations on
    four sides, none thin, and clear of the 1.6 mm FDM floor. The screw boss
    now starts at the seat floor instead of z=0, which is what stopped it
    refilling the recess (that was 14.87 mm3 of interference). Seated
    interference is now 0.0000 mm3, and the head stands 1.2 mm less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
    [EInk_Weather_Display_Assembly.FCStd, rear_cover.stl, rear_cover_foot.FCStd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]
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2026-09-22 fix(firmware): make FR-11's partial refresh actually reach the glass
    The partial path had never run. /api/status read partials_since_full: 0
    against fulls_total: 6, so every refresh was a full panel flash while the
    logs claimed partials. Three independent causes, all silent:
    - A partial needs the previous and next frames at once, and two 78,200-byte
    framebuffers do not fit this part (the only region large enough for one is
    113,840 bytes; the pair needs 156,400), so the second buffer failed to
    allocate on every tick. The frames are now REPRODUCED rather than stored:
    one buffer holds the page's static layer, the previous values live in a
    1.6 KB snapshot, and both frames are composed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
    [epd.h]
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2026-09-22 fix(secrets): seed the bench HA URL and token, not just the OWM key
    The generator never read HA_URL/HA_TOKEN from .env, so a device flashed with
    bench secrets came up with no Home Assistant address and every HA-bound box
    resolved empty — the reported symptom was "it complains that it doesn't have
    anything set up for HA, despite having it in the .env". The values were in the
    file the whole time; nothing emitted them.
    app_seed_ha() mirrors app_seed_owm_key()'s never-overwrite contract and writes
    only when BOTH url and token are supplied, so a bench build without HA leaves a
    provisioned device's stored credentials alone. A trailing slash is stripped on
    both sides because the firmware appends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
    [main.c]
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2026-09-24 feat(ota): update from GitHub releases, plus pre-release audit fixes
    OTA from the project's GitHub releases (FR-33): GET /api/ota/check reports
    whether a newer release exists; POST /api/ota/update installs it; and an
    opt-in boot-time auto-update installs on USB power before the first render.
    The device reads a flat manifest.json at the release's stable
    releases/latest/download path (no tag, no GitHub API token) and compares
    versions NUMERICALLY — as strings "0.10.0" < "0.9.0", which would hide every
    double-digit release. Parsing and comparison live in lib/otarelease so both
    are host-tested. Rollback protection remains the backstop.
    Audit fixes found before release:
    - /api/status returned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
    [main.c]
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2026-09-24 fix(ota): make the GitHub update actually work on the device
    Two defects, both invisible to the host suites and found only by pointing the
    device at the real release. Neither could have shipped silently — OTA simply
    never worked — but both looked like network problems in the log.
    1. The TLS handshake starved. Every fetch from an HTTP handler failed with
    `mbedtls_ssl_setup returned -0x7F00` (ALLOC_FAILED), and the endpoint answered
    in ~0.12 s, which is the tell that no handshake was ever attempted. The render
    task holds its 78,200-byte static layer resident between ticks (USB/mains), and
    the handshake needs the ONE contiguous DRAM region large enough for a
    framebuffer. The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
    [main.c]
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2026-09-25 fix(enclosure): slim the case to the cell and make the bezel bed edge printable
    The case depth is set entirely by the 11 mm cell, not the 4.3 mm board, so the only
    reclaimable slack was BATTERY_REAR_PAD 0.2 and GRID_ASSEMBLY_GAP 0.1. Both are now zero,
    the cell bears directly on the cover skin and the grid ribs, and CASE_D drops 18.70 -> 18.40.
    09_main_chassis_final.py had stale duplicate battery planes; it now imports them.
    The front bezel prints cosmetic-face-down, where the 3.4 mm circular roll left the bed nearly
    vertical, so the outer ~1.1 mm of the first layers printed in mid-air -- the reported "prints
    ugly". The roll is kept for its silhouette and only its outer arc is replaced by a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
    [EInk_Weather_Display_Assembly.FCStd, case_shell.FCStd, display_capture.FCStd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]
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
